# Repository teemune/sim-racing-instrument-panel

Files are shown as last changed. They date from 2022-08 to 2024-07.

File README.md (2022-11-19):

# sim-racing-instrument-panel
 Instruments for sim racing games
 
## SimHub Gear Display
Design files for electronics and FW included.

Works with SimHub Dash Studio, which generates the Arduino code. Standard Arduino bootloader needs to be flashed on the microcontroller first, to make it able to receive a firmware through USB.

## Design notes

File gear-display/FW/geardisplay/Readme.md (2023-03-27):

## Changes from SimHub default config:
### Change 7-segment display configuration:
There is a bug in the J-revision sketch.

The sketch version can be identified by rows:
~~~
// J revision sketch
#define VERSION 'j'
~~~

The byte array is described incorrectly:

~~~
byte g_6c595fontArray[] = {
  // dp-a-b-c-d-e-f-g
  0b00111111, // 0
  0b00000110, // 1
  0b01011011, // 2
  0b01001111, // 3
  0b01110010, // 4
  0b01101101, // 5
  0b01111101, // 6
  0b00000111, // 7
  0b00111111, // 8
  0b01101111, // 9
  0b00000000, // OFF empty
  0b11101111, // REVERSE SPEED
};
~~~

The configuration is actually:
~~~
// dp-g-f-e-d-c-b-a
~~~

to

#### Rev1 PCB:
~~~
byte g_6c595fontArray[] = {
  // a-b-c-d-e-f-g-dp
  0b11111100, // 0        
  0b01100000, // 1            
  0b11011010, // 2
  0b11110010, // 3
  0b01101010, // 4
  0b10110110, // 5
  0b10111110, // 6
  0b11100000, // 7
  0b11111100, // 8
  0b11110110, // 9
  0b00000000, // OFF empty
  0b11101111, // REVERSE SPEED
};
~~~

#### Rev2 PCB:
Designed for SimHub sketch template "J".
~~~
byte g_6c595fontArray[] = {
  // dp-g-f-e-d-c-b-a
  0b00111111, // 0        
  0b00000110, // 1            
  0b01011011, // 2
  0b01001111, // 3
  0b01110010, // 4
  0b01101101, // 5
  0b01111101, // 6
  0b00000111, // 7
  0b00111111, // 8
  0b01101111, // 9
  0b00000000, // OFF empty
  0b11101111, // REVERSE SPEED
};
~~~

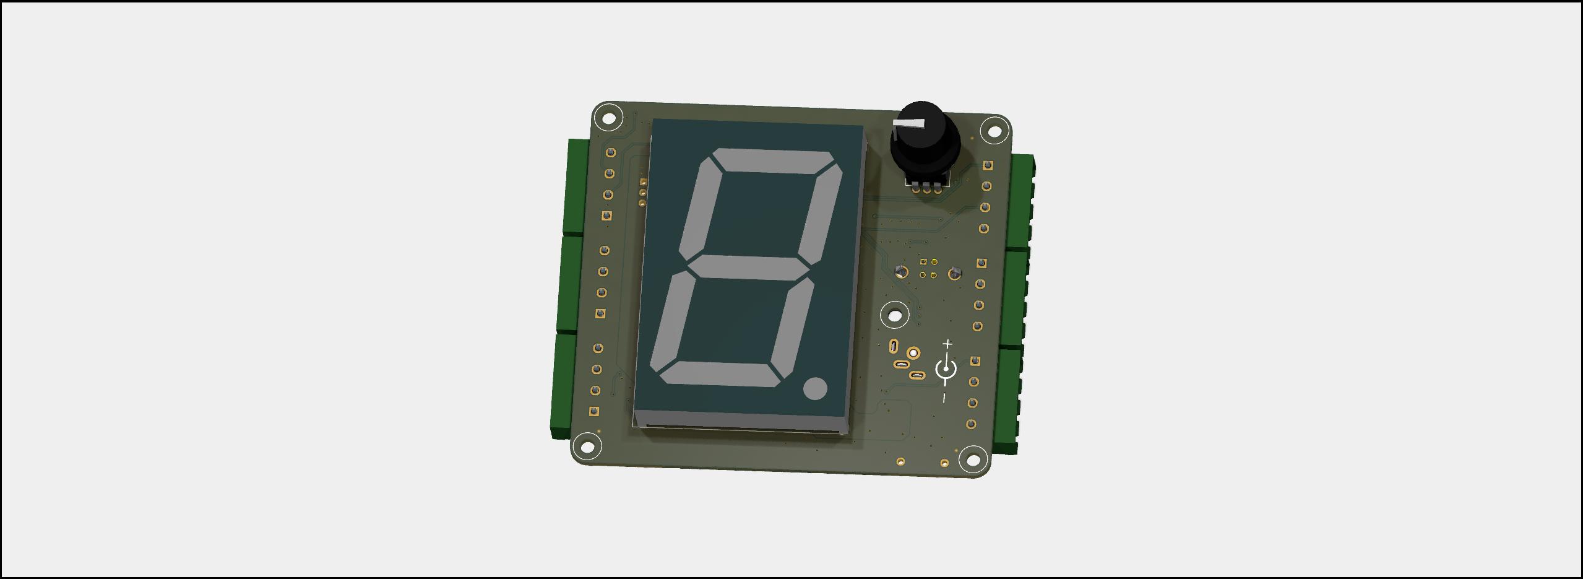
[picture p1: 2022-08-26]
gear-display/PCB/GDBM/pic/GDBM_R.jpg

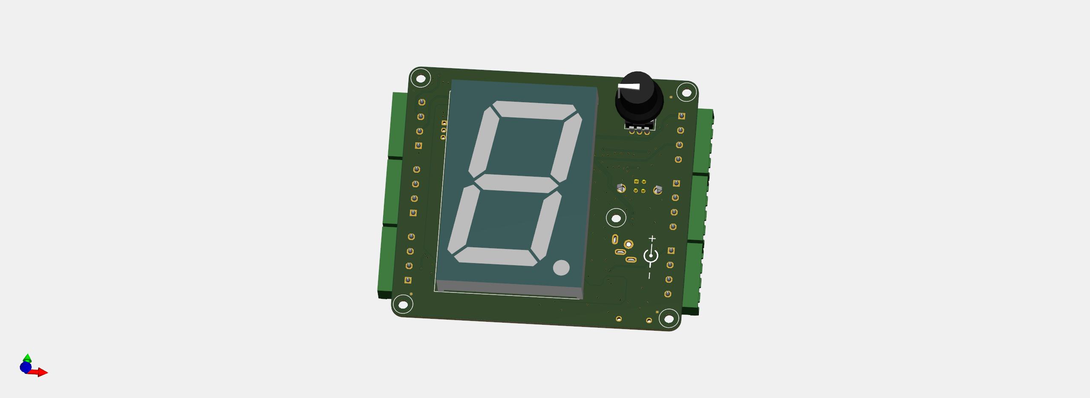
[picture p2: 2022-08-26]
gear-display/PCB/GDBM/pic/GDBM.jpg

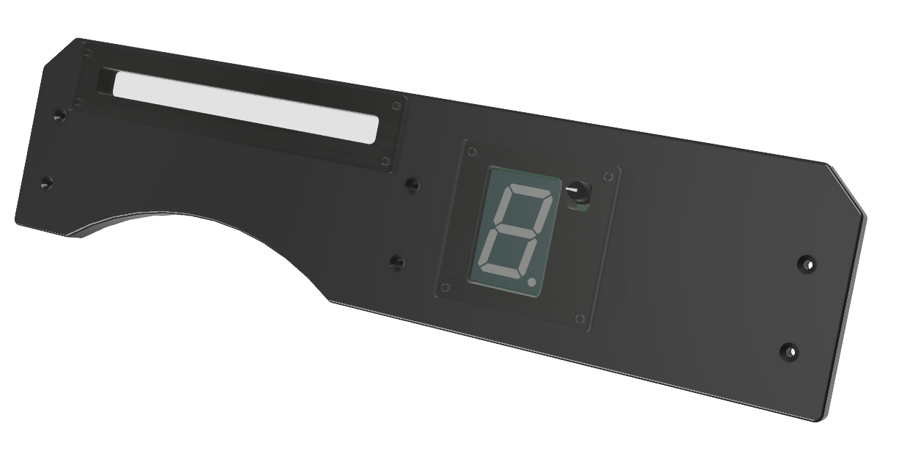
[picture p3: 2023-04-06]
gear-display/Dashboard v6.png

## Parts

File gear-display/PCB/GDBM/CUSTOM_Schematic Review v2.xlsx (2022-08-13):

Product: | Cure Rev B
Review date: | 0.4407638889
Reviewer: | Teemu Latonen
No | Item | Status | Comments
1 | Documentation
1.1 | New components checked for errors | x
1.2 | Schematic and test point comments
1.3 | Revision etc updated | x
1.4 | Change history page updated | x
2 | General design
2.1 | Check that floating pins are ok to be left floating | x
2.2 | Is there room for more bypass capacitors
2.3 | Design rules
2.4 | Combine R and C values and sizes | x
3 | Digital circuits
3.1 | Impedance matching | x
3.2 | Logic voltage levels | x
3.3 | Logic timings during boot up | x
4 | Analog circuits
4.1 | Op amps: Offset voltage, bias current, speed, output load capability | x
 | Capacitive loading | x
4.2 | Input ranges for analog circuits | x
4.3 | Overvoltage situations | x
5 | Power circuits
5.1 | Power outputs are short circuit proof | x
5.2 | Power input is polarity protected | x
5.3 | Fuses and TVSs are added | x
6 | EMC
6.1 | Input and output signals are filtered | x
6.2 | Critical signals (RESET etc) are protected from EMI | x
6.3 | Fast signals are suppressed (e.g. high frequency clocks, SMPS) | x
6.4 | Emissions from SMPS are analyzed and proper countermeasures used
7 | Testing and production
7.1 | Test points, GND connection point
7.2 | 0 Ohm resistors to isolate circuits | x
7.3 | Alignment holes for tester | x
7.4 | All parts are RoHS compliant | x
8 | BOM
8.1 | Component availability and lead times

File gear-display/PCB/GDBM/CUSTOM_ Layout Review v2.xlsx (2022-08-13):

Product: | Cure
Review date: | 10.1.2022
Reviewer: | Teemu Latonen
No | Item | Status | Comments
1 | Markings
1.1 | PN, revision etc marked on board |  | ok
1.2 | Area marked for UL and manufacturer markings
1.3 | Layers marked for 4+ layer boards |  | ok
1.4 | Reference designators |  | ok
1.5 | PCB Build up in drill drawing
2 | Design
2.1 | Spark gaps and clearance cut outs |  | ok
2.2 | Fiducials |  | ok
2.3 | Clerances and creepage distances checked |  | ok
2.4 | Corners rounded (0.5 mm) |  | ok
2.5 | Cable clearances, receptacles fit to connectors |  | ok
2.6 | Component clearances |  | ok
2.7 | Mounting holes |  | ok
2.8 | PCB break away tabs |  | Not needed
2.9 | Polarization of components (pin 1 marked, connectors labeled) |  | Diode footprint could be improved
2.10 | No traces under conductive components |  | ok
2.11 | No direct traces between adjacent pads of IC, if not covered by solder mask |  | ok
2.12 | Tester guidance holes |  | ok
2.13 | > 5 mm distance between test points |  | No test points
2.14 | Reset traces short |  | well…
2.15 | Ground planes for analog circuits |  | ok
2.16 | Impedance matching |  | ok
2.17 | Area for heat sinks or exposed copper on PCB |  | ok
2.18 | Wave soldering requirements
2.19 | Hand soldering requirements |  | not optimal
3 | Documents
3.1 | BOM
3.2 | Gerbers
3.3 | Placement ASCII file
3.4 | Assembly drawing
4 | OTHER
4.1 | PCB and silk color
4.2 | Surface finish

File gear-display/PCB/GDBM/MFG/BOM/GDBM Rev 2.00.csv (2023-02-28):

Source: | C:\GitHubProjects\sim-racing-instrument-panel\gear-display\PCB\GDBM\GDBM.kicad_sch
Date: | 28/02/2023 22.51.25
Tool: | Eeschema (6.0.0)
Generator: | C:\Program Files\KiCad\6.0\bin\scripting\plugins/bom_csv_grouped_by_value.py
Component Count: | 94
Individual Components:
Item | Qty | Reference(s) | Value | LibPart | Footprint | Datasheet | Code | DNP | MFG_PartNo | Manufacturer | Price | Supplier | Supplier_PartNo
 |  | C1 | C_1206_10u_X5R_50V_automotive | KD_Capacitor:C_1206_10u_X5R_50V_automotive | KD_Capacitor:CAPC3216X150N | https://search.murata.co.jp/Ceramy/image/img/A01X/G101/ENG/GRT31CR61H106ME01-01.pdf | 10u | F | GRT31CR61H106ME01L | Murata Electronics | 0.30 | Digi-Key | 490-12457-1-ND
 |  | C2 | C_1206_10u_X5R_50V_automotive | KD_Capacitor:C_1206_10u_X5R_50V_automotive | KD_Capacitor:CAPC3216X150N | https://search.murata.co.jp/Ceramy/image/img/A01X/G101/ENG/GRT31CR61H106ME01-01.pdf | 10u | F | GRT31CR61H106ME01L | Murata Electronics | 0.30 | Digi-Key | 490-12457-1-ND
 |  | C3 | C_1206_10u_X5R_50V_automotive | KD_Capacitor:C_1206_10u_X5R_50V_automotive | KD_Capacitor:CAPC3216X150N | https://search.murata.co.jp/Ceramy/image/img/A01X/G101/ENG/GRT31CR61H106ME01-01.pdf | 10u | F | GRT31CR61H106ME01L | Murata Electronics | 0.30 | Digi-Key | 490-12457-1-ND
 |  | C4 | C_0603_100n_X7R_100V | KD_Capacitor:C_0603_100n_X7R_100V | KD_Capacitor:CAPC1608X90N | https://media.digikey.com/pdf/Data%20Sheets/Samsung%20PDFs/CL10B104KC8NNNC_Spec.pdf | 100n | F | CL10B104KC8NNNC | Samsung Electro-Mechanics | 0.03 | Digi-Key | 1276-6807-1-ND
 |  | C5 | C_0603_100n_X7R_100V | KD_Capacitor:C_0603_100n_X7R_100V | KD_Capacitor:CAPC1608X90N | https://media.digikey.com/pdf/Data%20Sheets/Samsung%20PDFs/CL10B104KC8NNNC_Spec.pdf | 100n | F | CL10B104KC8NNNC | Samsung Electro-Mechanics | 0.03 | Digi-Key | 1276-6807-1-ND
 |  | C6 | C_0603_100n_X7R_100V | KD_Capacitor:C_0603_100n_X7R_100V | KD_Capacitor:CAPC1608X90N | https://media.digikey.com/pdf/Data%20Sheets/Samsung%20PDFs/CL10B104KC8NNNC_Spec.pdf | 100n | F | CL10B104KC8NNNC | Samsung Electro-Mechanics | 0.03 | Digi-Key | 1276-6807-1-ND
 |  | C7 | C_0805_1u_X7R_25V | KD_Capacitor:C_0805_1u_X7R_25V | KD_Capacitor:CAPC2012X135N | https://api.kemet.com/component-edge/download/datasheet/CBR08C279B5GAC.pdf | 1u | F | CL21B105KAFNNNE | Kemet | 0.03 | Digi-Key | 1276-1066-1-ND
 |  | C8 | C_0603_33p_NP0_5%_100V | KD_Capacitor:C_0603_33p_NP0_5%_100V | KD_Capacitor:CAPC1608X90N | http://www.passivecomponent.com/wp-content/uploads/datasheet/WTC_MLCC_General_Purpose.pdf | 33p | F | C0603C330J1GAC7867 | KEMET | 0.05 | Digi-Key | 399-C0603C330J1GAC7867CT-ND
 |  | C9 | C_0805_1u_X7R_25V | KD_Capacitor:C_0805_1u_X7R_25V | KD_Capacitor:CAPC2012X135N | https://api.kemet.com/component-edge/download/datasheet/CBR08C279B5GAC.pdf | 1u | F | CL21B105KAFNNNE | Kemet | 0.03 | Digi-Key | 1276-1066-1-ND
 |  | C10 | C_0603_33p_NP0_5%_100V | KD_Capacitor:C_0603_33p_NP0_5%_100V | KD_Capacitor:CAPC1608X90N | http://www.passivecomponent.com/wp-content/uploads/datasheet/WTC_MLCC_General_Purpose.pdf | 33p | F | C0603C330J1GAC7867 | KEMET | 0.05 | Digi-Key | 399-C0603C330J1GAC7867CT-ND
 |  | C11 | C_0805_1u_X7R_25V | KD_Capacitor:C_0805_1u_X7R_25V | KD_Capacitor:CAPC2012X135N | https://api.kemet.com/component-edge/download/datasheet/CBR08C279B5GAC.pdf | 1u | F | CL21B105KAFNNNE | Kemet | 0.03 | Digi-Key | 1276-1066-1-ND
 |  | C12 | C_1206_10u_X5R_50V_automotive | KD_Capacitor:C_1206_10u_X5R_50V_automotive | KD_Capacitor:CAPC3216X150N | https://search.murata.co.jp/Ceramy/image/img/A01X/G101/ENG/GRT31CR61H106ME01-01.pdf | 10u | F | GRT31CR61H106ME01L | Murata Electronics | 0.30 | Digi-Key | 490-12457-1-ND
 |  | C13 | C_0603_100n_X7R_100V | KD_Capacitor:C_0603_100n_X7R_100V | KD_Capacitor:CAPC1608X90N | https://media.digikey.com/pdf/Data%20Sheets/Samsung%20PDFs/CL10B104KC8NNNC_Spec.pdf | 100n | F | CL10B104KC8NNNC | Samsung Electro-Mechanics | 0.03 | Digi-Key | 1276-6807-1-ND
 |  | C14 | C_0603_100n_X7R_100V | KD_Capacitor:C_0603_100n_X7R_100V | KD_Capacitor:CAPC1608X90N | https://media.digikey.com/pdf/Data%20Sheets/Samsung%20PDFs/CL10B104KC8NNNC_Spec.pdf | 100n | F | CL10B104KC8NNNC | Samsung Electro-Mechanics | 0.03 | Digi-Key | 1276-6807-1-ND
 |  | C15 | C_0805_DNP | KD_Capacitor:C_0805_DNP | KD_Capacitor:CAPC2012X135N_DNP | https://api.kemet.com/component-edge/download/datasheet/CBR08C279B5GAC.pdf | DNP | T | DNP | DNP | 0.00 | DNP | DNP
 |  | C16 | C_1206_10u_X5R_50V_automotive | KD_Capacitor:C_1206_10u_X5R_50V_automotive | KD_Capacitor:CAPC3216X150N | https://search.murata.co.jp/Ceramy/image/img/A01X/G101/ENG/GRT31CR61H106ME01-01.pdf | 10u | F | GRT31CR61H106ME01L | Murata Electronics | 0.30 | Digi-Key | 490-12457-1-ND
 |  | C17 | C_1206_10u_X5R_50V_automotive | KD_Capacitor:C_1206_10u_X5R_50V_automotive | KD_Capacitor:CAPC3216X150N | https://search.murata.co.jp/Ceramy/image/img/A01X/G101/ENG/GRT31CR61H106ME01-01.pdf | 10u | F | GRT31CR61H106ME01L | Murata Electronics | 0.30 | Digi-Key | 490-12457-1-ND
 |  | C18 | C_0603_100n_X7R_100V | KD_Capacitor:C_0603_100n_X7R_100V | KD_Capacitor:CAPC1608X90N | https://media.digikey.com/pdf/Data%20Sheets/Samsung%20PDFs/CL10B104KC8NNNC_Spec.pdf | 100n | F | CL10B104KC8NNNC | Samsung Electro-Mechanics | 0.03 | Digi-Key | 1276-6807-1-ND
 |  | C19 | C_0603_100n_X7R_100V | KD_Capacitor:C_0603_100n_X7R_100V | KD_Capacitor:CAPC1608X90N | https://media.digikey.com/pdf/Data%20Sheets/Samsung%20PDFs/CL10B104KC8NNNC_Spec.pdf | 100n | F | CL10B104KC8NNNC | Samsung Electro-Mechanics | 0.03 | Digi-Key | 1276-6807-1-ND
 |  | C20 | C_0805_DNP | KD_Capacitor:C_0805_DNP | KD_Capacitor:CAPC2012X135N_DNP | https://api.kemet.com/component-edge/download/datasheet/CBR08C279B5GAC.pdf | DNP | T | DNP | DNP | 0.00 | DNP | DNP
 |  | C21 | C_0805_1u_X7R_25V | KD_Capacitor:C_0805_1u_X7R_25V | KD_Capacitor:CAPC2012X135N | https://api.kemet.com/component-edge/download/datasheet/CBR08C279B5GAC.pdf | 1u | F | CL21B105KAFNNNE | Kemet | 0.03 | Digi-Key | 1276-1066-1-ND
 |  | C22 | C_0805_22u_X5R_10V | KD_Capacitor:C_0805_22u_X5R_10V | KD_Capacitor:CAPC2012X135N | https://www.samsungsem.com/kr/support/product-search/mlcc/CL21A226MPQNNNE.jsp | 22u | F | CL21A226MPQNNNE | Samsung Electro-Mechanics | 0.15 | Digi-Key | 1276-2910-1-ND
 |  | C23 | C_0603_10n_X7R_100V | KD_Capacitor:C_0603_10n_X7R_100V | KD_Capacitor:CAPC1608X90N |  | 10n | F | C1608X7R2A103K080AA | TDK Corporation | 0.05 | Digi-Key | 445-1304-1-ND
 |  | C24 | C_0603_10n_X7R_100V | KD_Capacitor:C_0603_10n_X7R_100V | KD_Capacitor:CAPC1608X90N |  | 10n | F | C1608X7R2A103K080AA | TDK Corporation | 0.05 | Digi-Key | 445-1304-1-ND
 |  | C25 | C_1206_10u_X5R_50V_automotive | KD_Capacitor:C_1206_10u_X5R_50V_automotive | KD_Capacitor:CAPC3216X150N | https://search.murata.co.jp/Ceramy/image/img/A01X/G101/ENG/GRT31CR61H106ME01-01.pdf | 10u | F | GRT31CR61H106ME01L | Murata Electronics | 0.30 | Digi-Key | 490-12457-1-ND
 |  | D1 | Schottky_30V_1A_Toshiba_CUS10S30 | KD_Diode:Schottky_30V_1A_Toshiba_CUS10S30 | KD_Diode:D_SOD-323 | https://toshiba.semicon-storage.com/info/docget.jsp?did=14077&prodName=CUS10S30 | CUS10S30,H3F | F | CUS10S30,H3F | Toshiba Semiconductor and Storage | 0.2 | Digi-Key | CUS10S30H3FCT-ND
 |  | D2 | TVS_12V_LF_SMAJ12CA | KD_Diode:TVS_12V_LF_SMAJ12CA | KD_Diode:DIOC530X280X230_SMA_A | https://media.digikey.com/pdf/Data%20Sheets/AVX%20PDFs/Transient%20Suppression%20Diodes.pdf | SMAJ12A | F | SMAJ12A | Littelfuse Inc. | 0.3 | Digi-Key | SMAJ12ALFCT-ND
 |  | D3 | 0603_Green_Clear_LTST-C190KGKT | KD_Led:0603_Green_Clear_LTST-C190KGKT | KD_Diode:DIOC1608X70 | https://optoelectronics.liteon.com/upload/download/DS22-2000-074/LTST-C190KGKT.PDF | Green Clear | F | LTST-C190KGKT | Lite-On Inc. | 0.05 | Digi-Key | 160-1435-1-ND
 |  | D4 | TVS_5V5_DRTR5V0U4S-7-M | KD_Diode:TVS_5V5_DRTR5V0U4S-7-M | KD_Package_TO_SOT_SMD:SOT-363_SC-70-6 | https://www.diodes.com/assets/Datasheets/DRTR5V0U4S.pdf | DRTR5V0U4S-7 | F | DRTR5V0U4S-7 | Diodes Incorporated | 0.30 | Digi-Key | DRTR5V0U4S-7DICT-ND
 |  | D5 | 7seg_70mm_CA_Lumex_LDS-AD16RI | KD_Display:7seg_70mm_CA_Lumex_LDS-AD16RI | KD_Display:7seg_70mm_Kingbright_SC23-11SURKWA | datasheet | LDS-AD16RI | F | LDS-AD16RI | Lumex Opto/Components Inc. | 13 | Digi-Key | 67-1493-ND
 |  | D6 | Schottky_30V_1A_Toshiba_CUS10S30 | KD_Diode:Schottky_30V_1A_Toshiba_CUS10S30 | KD_Diode:D_SOD-323 | https://toshiba.semicon-storage.com/info/docget.jsp?did=14077&prodName=CUS10S30 | CUS10S30,H3F | F | CUS10S30,H3F | Toshiba Semiconductor and Storage | 0.2 | Digi-Key | CUS10S30H3FCT-ND
 |  | D7 | Schottky_30V_1A_Toshiba_CUS10S30 | KD_Diode:Schottky_30V_1A_Toshiba_CUS10S30 | KD_Diode:D_SOD-323 | https://toshiba.semicon-storage.com/info/docget.jsp?did=14077&prodName=CUS10S30 | CUS10S30,H3F | F | CUS10S30,H3F | Toshiba Semiconductor and Storage | 0.2 | Digi-Key | CUS10S30H3FCT-ND
 |  | F1 | Fuse_1A_C1F_1 | KD_Devices_Other:Fuse_1A_C1F_1 | KD_Resistor:RESC3216X70N | https://belfuse.com/resources/datasheets/circuitprotection/ds-cp-c1f-series.pdf | Fuse 1 A | F | C1F 1 | Bel Fuse Inc. | 0.15 | Digi-Key | 507-1878-1-ND
 |  | FB1 | Ferrite_250mA_Murata_BLM15HG102SN1D | KD_Inductor:Ferrite_250mA_Murata_BLM15HG102SN1D | KD_Inductor:INDC1005X55N | datasheet | BLM15HG102SN1D | F | BLM15HG102SN1D | Murata Electronics | 0.10 | Digi-Key | 490-3999-1-ND
 |  | H1 | NPTH_3.2_M3_Clearance | KD_Mechanical_Mounting_Hole:NPTH_3.2_M3_Clearance | KD_Mechanical_Mounting_Hole:NPTH_3.2mm_M3_clearance |  | 3.2 mm hole | T | DNP | DNP | 0.00 | DNP | DNP
 |  | H3 | NPTH_3.2_M3_Clearance | KD_Mechanical_Mounting_Hole:NPTH_3.2_M3_Clearance | KD_Mechanical_Mounting_Hole:NPTH_3.2mm_M3_clearance |  | 3.2 mm hole | T | DNP | DNP | 0.00 | DNP | DNP
 |  | H4 | NPTH_3.2_M3_Clearance | KD_Mechanical_Mounting_Hole:NPTH_3.2_M3_Clearance | KD_Mechanical_Mounting_Hole:NPTH_3.2mm_M3_clearance |  | 3.2 mm hole | T | DNP | DNP | 0.00 | DNP | DNP
 |  | H5 | NPTH_3.2_M3_Clearance | KD_Mechanical_Mounting_Hole:NPTH_3.2_M3_Clearance | KD_Mechanical_Mounting_Hole:NPTH_3.2mm_M3_clearance |  | 3.2 mm hole | T | DNP | DNP | 0.00 | DNP | DNP
 |  | H6 | NPTH_3.2_M3_Clearance | KD_Mechanical_Mounting_Hole:NPTH_3.2_M3_Clearance | KD_Mechanical_Mounting_Hole:NPTH_3.2mm_M3_clearance |  | 3.2 mm hole | T | DNP | DNP | 0.00 | DNP | DNP
 |  | J1 | Con_Screw_1x04_691313510004 | KD_Connector_Screw:Con_Screw_1x04_691313510004 | KD_Connector_Screw:CON_508_1X04_691313510004_Mated | https://www.we-online.com/katalog/datasheet/6913135100xx.pdf | 1x04 | F | 691313510004 | Würth Elektronik | 0.3 | Digi-Key | 732-2072-ND
 |  | J2 | Con_Screw_1x04_691313510004 | KD_Connector_Screw:Con_Screw_1x04_691313510004 | KD_Connector_Screw:CON_508_1X04_691313510004_Mated | https://www.we-online.com/katalog/datasheet/6913135100xx.pdf | 1x04 | F | 691313510004 | Würth Elektronik | 0.3 | Digi-Key | 732-2072-ND
 |  | J3 | DC_2.1_5.5_54-00286 | KD_Connector_Circular:DC_2.1_5.5_54-00286 | KD_Connector_Circular:CON_DC_2.1_5.5_Tensility_54-00286 | http://www.tensility.com/pdffiles/54-00286.pdf | 2.1 mm DC | F | 54-00286 | CUI Devices | 0.7 | Digi-Key | 839-54-00286-ND
 |  | J4 | Con_Screw_1x04_691313510004 | KD_Connector_Screw:Con_Screw_1x04_691313510004 | KD_Connector_Screw:CON_508_1X04_691313510004_Mated | https://www.we-online.com/katalog/datasheet/6913135100xx.pdf | 1x04 | F | 691313510004 | Würth Elektronik | 0.3 | Digi-Key | 732-2072-ND
 |  | J5 | Con_Screw_1x04_691313510004 | KD_Connector_Screw:Con_Screw_1x04_691313510004 | KD_Connector_Screw:CON_508_1X04_691313510004_Mated | https://www.we-online.com/katalog/datasheet/6913135100xx.pdf | 1x04 | F | 691313510004 | Würth Elektronik | 0.3 | Digi-Key | 732-2072-ND
 |  | J6 | Con_Screw_1x04_691313510004 | KD_Connector_Screw:Con_Screw_1x04_691313510004 | KD_Connector_Screw:CON_508_1X04_691313510004_Mated | https://www.we-online.com/katalog/datasheet/6913135100xx.pdf | 1x04 | F | 691313510004 | Würth Elektronik | 0.3 | Digi-Key | 732-2072-ND
 |  | J7 | Con_Screw_1x04_691313510004 | KD_Connector_Screw:Con_Screw_1x04_691313510004 | KD_Connector_Screw:CON_508_1X04_691313510004_Mated | https://www.we-online.com/katalog/datasheet/6913135100xx.pdf | 1x04 | F | 691313510004 | Würth Elektronik | 0.3 | Digi-Key | 732-2072-ND
 |  | J8 | USB_B_V_Adam_USB-B-S-VT | KD_Connector_USB_HDMI_Etc:USB_B_V_Adam_USB-B-S-VT | KD_Connector_USB_HDMI_Etc:USB_B_Vertical_Adam_USB-B-S-VT | https://app.adam-tech.com/products/download/data_sheet/195855/usb-b-s-vt-data-sheet.pdf | USB Mini B | F | USB-B-S-VT | Adam Tech | 1 | Digi-Key | 2057-USB-B-S-VT-ND
 |  | M1 | Knob_6mm_BL_RED_CLIFF_CL170842CR | KD_Mechanical:Knob_6mm_BL_RED_CLIFF_CL170842CR | KD_Mechanical:Knob_CLIFF_CL170842CR |  | CL170842CR | F | CL170842CR | CLIFF Electronic Components Ltd | 1 | Digi-Key | 3185-CL170842CR-ND
 |  | Q1 | PMOS_30V_4A1_SIL3407-TP | KD_Transistor_FET:PMOS_30V_4A1_SIL3407-TP | KD_Package_TO_SOT_SMD:SOT95P280X120-6RN | https://www.mccsemi.com/pdf/Products/SIL3407(SOT23-6L).pdf | SIL3407-TP | F | SIL3407-TP | Micro Commercial Co | 0.4 | Digi-Key | 353-SIL3407-TPCT-ND
 |  | R1 | R_0805_DNP | KD_Resistor:R_0805_DNP | KD_Resistor:RESC2012X60N_DNP |  | DNP | T | DNP | DNP | 0.00 | DNP | DNP
 |  | R2 | R_0603_22k_1% | KD_Resistor:R_0603_22k_1% | KD_Resistor:RESC1608X55N | https://www.yageo.com/upload/media/product/productsearch/datasheet/rchip/PYu-RC_Group_51_RoHS_L_11.pdf | 22k | F | 311-22.0KHRCT-ND | YAGEO | 0.01 | Digi-Key | 311-22.0KHRCT-ND
 |  | R3 | R_0603_360_1% | KD_Resistor:R_0603_360_1% | KD_Resistor:RESC1608X55N | https://www.yageo.com/upload/media/product/productsearch/datasheet/rchip/PYu-RT_1-to-0.01_RoHS_L_12.pdf | 360 | F | RT0603FRE07360RL | YAGEO | 0.02 | Digi-Key | 13-RT0603FRE07360RLCT-ND
 |  | R4 | R_0603_22k_1% | KD_Resistor:R_0603_22k_1% | KD_Resistor:RESC1608X55N | https://www.yageo.com/upload/media/product/productsearch/datasheet/rchip/PYu-RC_Group_51_RoHS_L_11.pdf | 22k | F | 311-22.0KHRCT-ND | YAGEO | 0.01 | Digi-Key | 311-22.0KHRCT-ND
 |  | R5 | R_0603_DNP | KD_Resistor:R_0603_DNP | KD_Resistor:RESC1608X55N_DNP |  | DNP | T | DNP | DNP | 0.00 | DNP | DNP
 |  | R6 | R_0603_360_1% | KD_Resistor:R_0603_360_1% | KD_Resistor:RESC1608X55N | https://www.yageo.com/upload/media/product/productsearch/datasheet/rchip/PYu-RT_1-to-0.01_RoHS_L_12.pdf | 360 | F | RT0603FRE07360RL | YAGEO | 0.02 | Digi-Key | 13-RT0603FRE07360RLCT-ND
 |  | R7 | R_0603_360_1% | KD_Resistor:R_0603_360_1% | KD_Resistor:RESC1608X55N | https://www.yageo.com/upload/media/product/productsearch/datasheet/rchip/PYu-RT_1-to-0.01_RoHS_L_12.pdf | 360 | F | RT0603FRE07360RL | YAGEO | 0.02 | Digi-Key | 13-RT0603FRE07360RLCT-ND
 |  | R8 | R_0402_DNP | KD_Resistor:R_0402_DNP | KD_Resistor:RESC1005X40N |  | DNP | T | DNP | DNP | 0.00 | DNP | DNP
 |  | R9 | R_0603_10_5% | KD_Resistor:R_0603_10_5% | KD_Resistor:RESC1608X55N | https://www.te.com/commerce/DocumentDelivery/DDEController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 | 10 | F | WR06X100 JTL | Walsin Technology Corporation | 0.01 | Digi-Key | 1292-WR06X100JTLCT-ND
 |  | R10 | R_0603_10_5% | KD_Resistor:R_0603_10_5% | KD_Resistor:RESC1608X55N | https://www.te.com/commerce/DocumentDelivery/DDEController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 | 10 | F | WR06X100 JTL | Walsin Technology Corporation | 0.01 | Digi-Key | 1292-WR06X100JTLCT-ND
 |  | R11 | R_1206_191_1% | KD_Resistor:R_1206_191_1% | KD_Resistor:RESC3216X70N | https://www.yageo.com/upload/media/product/productsearch/datasheet/rchip/PYu-RC_Group_51_RoHS_L_11.pdf | 191 | F | RC1206FR-07191RL | YAGEO | 0.05 | Digi-Key | 311-191FRCT-ND
 |  | R12 | R_1206_191_1% | KD_Resistor:R_1206_191_1% | KD_Resistor:RESC3216X70N | https://www.yageo.com/upload/media/product/productsearch/datasheet/rchip/PYu-RC_Group_51_RoHS_L_11.pdf | 191 | F | RC1206FR-07191RL | YAGEO | 0.05 | Digi-Key | 311-191FRCT-ND
 |  | R13 | R_1206_191_1% | KD_Resistor:R_1206_191_1% | KD_Resistor:RESC3216X70N | https://www.yageo.com/upload/media/product/productsearch/datasheet/rchip/PYu-RC_Group_51_RoHS_L_11.pdf | 191 | F | RC1206FR-07191RL | YAGEO | 0.05 | Digi-Key | 311-191FRCT-ND
 |  | R14 | R_1206_191_1% | KD_Resistor:R_1206_191_1% | KD_Resistor:RESC3216X70N | https://www.yageo.com/upload/media/product/productsearch/datasheet/rchip/PYu-RC_Group_51_RoHS_L_11.pdf | 191 | F | RC1206FR-07191RL | YAGEO | 0.05 | Digi-Key | 311-191FRCT-ND
 |  | R15 | R_0603_22k_1% | KD_Resistor:R_0603_22k_1% | KD_Resistor:RESC1608X55N | https://www.yageo.com/upload/media/product/productsearch/datasheet/rchip/PYu-RC_Group_51_RoHS_L_11.pdf | 22k | F | 311-22.0KHRCT-ND | YAGEO | 0.01 | Digi-Key | 311-22.0KHRCT-ND
 |  | R16 | R_1206_191_1% | KD_Resistor:R_1206_191_1% | KD_Resistor:RESC3216X70N | https://www.yageo.com/upload/media/product/productsearch/datasheet/rchip/PYu-RC_Group_51_RoHS_L_11.pdf | 191 | F | RC1206FR-07191RL | YAGEO | 0.05 | Digi-Key | 311-191FRCT-ND
 |  | R17 | R_1206_191_1% | KD_Resistor:R_1206_191_1% | KD_Resistor:RESC3216X70N | https://www.yageo.com/upload/media/product/productsearch/datasheet/rchip/PYu-RC_Group_51_RoHS_L_11.pdf | 191 | F | RC1206FR-07191RL | YAGEO | 0.05 | Digi-Key | 311-191FRCT-ND
 |  | R18 | R_1206_191_1% | KD_Resistor:R_1206_191_1% | KD_Resistor:RESC3216X70N | https://www.yageo.com/upload/media/product/productsearch/datasheet/rchip/PYu-RC_Group_51_RoHS_L_11.pdf | 191 | F | RC1206FR-07191RL | YAGEO | 0.05 | Digi-Key | 311-191FRCT-ND
 |  | R19 | R_1206_191_1% | KD_Resistor:R_1206_191_1% | KD_Resistor:RESC3216X70N | https://www.yageo.com/upload/media/product/productsearch/datasheet/rchip/PYu-RC_Group_51_RoHS_L_11.pdf | 191 | F | RC1206FR-07191RL | YAGEO | 0.05 | Digi-Key | 311-191FRCT-ND
 |  | R20 | R_0805_0_automotive | KD_Resistor:R_0805_0_automotive | KD_Resistor:RESC2012X60N | https://www.seielect.com/catalog/sei-rmcf_rmcp.pdf | 0 | F | RMCF0805ZT0R00 | Stackpole Electronics Inc | 0.01 | Digi-Key | RMCF0805ZT0R00CT-ND
 |  | R21 | R_0805_0_automotive | KD_Resistor:R_0805_0_automotive | KD_Resistor:RESC2012X60N | https://www.seielect.com/catalog/sei-rmcf_rmcp.pdf | 0 | F | RMCF0805ZT0R00 | Stackpole Electronics Inc | 0.01 | Digi-Key | RMCF0805ZT0R00CT-ND
 |  | R22 | R_0805_DNP | KD_Resistor:R_0805_DNP | KD_Resistor:RESC2012X60N_DNP | https://www.seielect.com/catalog/sei-rmcf_rmcp.pdf | DNP | T | DNP | DNP | 0.00 | DNP | DNP
 |  | R23 | R_0805_0_automotive | KD_Resistor:R_0805_0_automotive | KD_Resistor:RESC2012X60N | https://www.seielect.com/catalog/sei-rmcf_rmcp.pdf | 0 | F | RMCF0805ZT0R00 | Stackpole Electronics Inc | 0.01 | Digi-Key | RMCF0805ZT0R00CT-ND
 |  | R24 | R_0805_0_automotive | KD_Resistor:R_0805_0_automotive | KD_Resistor:RESC2012X60N | https://www.seielect.com/catalog/sei-rmcf_rmcp.pdf | 0 | F | RMCF0805ZT0R00 | Stackpole Electronics Inc | 0.01 | Digi-Key | RMCF0805ZT0R00CT-ND
 |  | R25 | R_0805_0_automotive | KD_Resistor:R_0805_0_automotive | KD_Resistor:RESC2012X60N | https://www.seielect.com/catalog/sei-rmcf_rmcp.pdf | 0 | F | RMCF0805ZT0R00 | Stackpole Electronics Inc | 0.01 | Digi-Key | RMCF0805ZT0R00CT-ND
 |  | R26 | R_0603_22k_1% | KD_Resistor:R_0603_22k_1% | KD_Resistor:RESC1608X55N | https://www.yageo.com/upload/media/product/productsearch/datasheet/rchip/PYu-RC_Group_51_RoHS_L_11.pdf | 22k | F | 311-22.0KHRCT-ND | YAGEO | 0.01 | Digi-Key | 311-22.0KHRCT-ND
 |  | R27 | R_0603_22k_1% | KD_Resistor:R_0603_22k_1% | KD_Resistor:RESC1608X55N | https://www.yageo.com/upload/media/product/productsearch/datasheet/rchip/PYu-RC_Group_51_RoHS_L_11.pdf | 22k | F | 311-22.0KHRCT-ND | YAGEO | 0.01 | Digi-Key | 311-22.0KHRCT-ND
 |  | R28 | Pot_V_10k_CUI_PT01-D120K2-B103 | KD_Resistor:Pot_V_50k_CUI_PT01-D225D-A503 | KD_Resistor:Potentiometer_CUI_PT01-DX20K2-XXXX | https://www.cuidevices.com/product/resource/pt01.pdf | 50k | F | PT01-D225D-A503 | CUI Devices | 0.77 | Digi-Key | 2223-PT01-D225D-A503-ND
 |  | R29 | R_0603_DNP | KD_Resistor:R_0603_DNP | KD_Resistor:RESC1608X55N_DNP |  | DNP | T | DNP | DNP | 0.00 | DNP | DNP
 |  | R30 | R_0603_DNP | KD_Resistor:R_0603_DNP | KD_Resistor:RESC1608X55N_DNP |  | DNP | T | DNP | DNP | 0.00 | DNP | DNP
 |  | R31 | R_0402_4700_1% | KD_Resistor:R_0402_4700_1% | KD_Resistor:RESC1005X40N | https://www.te.com/commerce/DocumentDelivery/DDEController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 | 4k7 | F | CR0402-FX-4701GLF | Bourns Inc. | 0.01 | Digi-Key | CR0402-FX-4701GLFCT-ND
 |  | R32 | R_0402_4700_1% | KD_Resistor:R_0402_4700_1% | KD_Resistor:RESC1005X40N | https://www.te.com/commerce/DocumentDelivery/DDEController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 | 4k7 | F | CR0402-FX-4701GLF | Bourns Inc. | 0.01 | Digi-Key | CR0402-FX-4701GLFCT-ND
 |  | R33 | R_0805_1200_5% | KD_Resistor:R_0805_1200_5% | KD_Resistor:RESC2012X60N | https://www.seielect.com/catalog/sei-rmcf_rmcp.pdf | 1200 | F | RMCF0805FT1K20 | Stackpole Electronics Inc | 0.01 | Digi-Key | RMCF0805FT1K20CT-ND
 |  | TP1 | TestPoint_2.5mm_Round | KD_Connector_Pads:TestPoint_2.5mm_Round | KD_Connector_Pads:TestPoint_Pad_D2.5mm | DNP | DNP | T | DNP | DNP | 0.00 | DNP | DNP
 |  | TP2 | TestPoint_2.5mm_Round | KD_Connector_Pads:TestPoint_2.5mm_Round | KD_Connector_Pads:TestPoint_Pad_D2.5mm | DNP | DNP | T | DNP | DNP | 0.00 | DNP | DNP
 |  | U1 | DC_DC_5V_2A0_GAPTEC_OKI-78SR-5_H | KD_IC_Regulator_DC_Converter:DC_DC_5V_2A0_GAPTEC_OKI-78SR-5_H | KD_IC_DCDC_Converter:DC_DC_GAPTEC_OKI-78SR-5_H | https://gaptec-electronic.com/datenblaetter/LMS78_2.0R.pdf | LMS78_05-2.0R | F | LMS78_05-2.0R | GAPTEC Electronic | 5 | Digi-Key | 3182-LMS78_05-2.0R-ND
 |  | U2 | ATmega32U4-AU | KD_IC_MCU:ATmega32U4-AU | KD_Package_QFP:QFP80P1200X1200X120-44R_N | http://ww1.microchip.com/downloads/en/DeviceDoc/Atmel-7766-8-bit-AVR-ATmega16U4-32U4_Summary.pdf | ATMEGA32U4-AU | F | ATMEGA32U4-AU | Microchip Technology | 5.3 | Digi-Key | ATMEGA32U4-AU-ND
 |  | U3 | Gate_Driver_MCP1401T-E-OT | KD_IC_Buffer_Driver_Interface:Gate_Driver_MCP1401T-E-OT | KD_Package_TO_SOT_SMD:SOT95P280X145-5N | https://ww1.microchip.com/downloads/en/DeviceDoc/20002052D.pdf | MCP1401 | F | MCP1401T-E/OT | Microchip Technology | 0.7 | Digi-Key | MCP1401T-E/OTCT-ND
 |  | U4 | Shift_register_OC_8bit_STPIC6D595MTR | KD_IC_Buffer_Driver_Interface:Shift_register_OC_8bit_STPIC6D595MTR | KD_Package_SO:SOIC127P640X200-16N | https://www.st.com/content/ccc/resource/technical/document/datasheet/e5/1c/d3/4a/66/f5/41/dc/CD00163738.pdf/files/CD00163738.pdf/jcr:content/translations/en.C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 | STPIC6D595MTR | F | STPIC6D595MTR | STMicroelectronics | 0.9 | Digi-Key | 497-6329-1-ND
 |  | U5 | Timer_Oscillator_TLC555CDG4 | KD_IC_Other:Timer_Oscillator_TLC555CDG4 | KD_Package_SO:SOIC127P600X175-8 | https://www.ti.com/general/docs/suppproductinfo.tsp?distId=10 | TLC555CDG4 | F | TLC555CDG4 | Texas Instruments | 0.9 | Digi-Key | 296-52992-ND
 |  | U8 | Buffer_74LVC125AS14-13_DIODES | KD_IC_Buffer_Driver_Interface:Buffer_74LVC125AS14-13_DIODES | KD_Package_SO:SOIC127P600X175-14N | https://www.diodes.com/assets/Datasheets/74LVC125A.pdf | 74LVC125AS14-13 | F | 74LVC125AS14-13 | Diodes Incorporated | 0.4 | Digi-Key | 74LVC125AS14-13DICT-ND
 |  | X1 | Programming_AVR_ISP_Staggered_Holes | KD_Connector_Special:Programming_AVR_ISP_Staggered_Holes | KD_Connector_Pads:CON_PINHD_1X06_TH_OFFSET | datasheet | AVR ISP | T | DNP | DNP | 0.00 | DNP | DNP
 |  | X2 | CON_1x04_TH_staggered | KD_Connector_Pads:CON_1x04_TH_staggered | KD_Connector_Pads:CON_PINHD_1X04_TH_OFFSET |  | 1x04 DNP | T | DNP | DNP | 0.00 | DNP | DNP
 |  | X3 | CON_GND_Probe_Hook | KD_Connector_Pads:CON_GND_Probe_Hook | KD_Connector_Pads:GND_HOOK_M |  | DNP | T | DNP | DNP | 0.00 | DNP | DNP
 |  | Y1 | Crystal_16M_AS-16.000-18-SMD-TR | KD_Oscillator:Crystal_16M_AS-16.000-18-SMD-TR | KD_Oscillator:OSC_CRYSTAL_HC49_US_N | https://www.raltron.com/webproducts/specs/CRYSTAL/AS-16.000-18-SMD-TR.pdf | 16 MHz | F | AS-16.000-18-SMD-TR | Raltron Electronics | 0.00 | Digi-Key | 2151-AS-16.000-18-SMD-TRCT-ND
Collated Components:
Item | Qty | Reference(s) | Value | LibPart | Footprint | Datasheet | Code | DNP | MFG_PartNo | Manufacturer | Price | Supplier | Supplier_PartNo
1 | 7 | C1, C2, C3, C12, C16, C17, C25 | C_1206_10u_X5R_50V_automotive | KD_Capacitor:C_1206_10u_X5R_50V_automotive | KD_Capacitor:CAPC3216X150N | https://search.murata.co.jp/Ceramy/image/img/A01X/G101/ENG/GRT31CR61H106ME01-01.pdf | 10u | F | GRT31CR61H106ME01L | Murata Electronics | 0.30 | Digi-Key | 490-12457-1-ND
2 | 7 | C4, C5, C6, C13, C14, C18, C19 | C_0603_100n_X7R_100V | KD_Capacitor:C_0603_100n_X7R_100V | KD_Capacitor:CAPC1608X90N | https://media.digikey.com/pdf/Data%20Sheets/Samsung%20PDFs/CL10B104KC8NNNC_Spec.pdf | 100n | F | CL10B104KC8NNNC | Samsung Electro-Mechanics | 0.03 | Digi-Key | 1276-6807-1-ND
3 | 4 | C7, C9, C11, C21 | C_0805_1u_X7R_25V | KD_Capacitor:C_0805_1u_X7R_25V | KD_Capacitor:CAPC2012X135N | https://api.kemet.com/component-edge/download/datasheet/CBR08C279B5GAC.pdf | 1u | F | CL21B105KAFNNNE | Kemet | 0.03 | Digi-Key | 1276-1066-1-ND
4 | 2 | C8, C10 | C_0603_33p_NP0_5%_100V | KD_Capacitor:C_0603_33p_NP0_5%_100V | KD_Capacitor:CAPC1608X90N | http://www.passivecomponent.com/wp-content/uploads/datasheet/WTC_MLCC_General_Purpose.pdf | 33p | F | C0603C330J1GAC7867 | KEMET | 0.05 | Digi-Key | 399-C0603C330J1GAC7867CT-ND
5 | 2 | C15, C20 | C_0805_DNP | KD_Capacitor:C_0805_DNP | KD_Capacitor:CAPC2012X135N_DNP | https://api.kemet.com/component-edge/download/datasheet/CBR08C279B5GAC.pdf | DNP | T | DNP | DNP | 0.00 | DNP | DNP
6 | 1 | C22 | C_0805_22u_X5R_10V | KD_Capacitor:C_0805_22u_X5R_10V | KD_Capacitor:CAPC2012X135N | https://www.samsungsem.com/kr/support/product-search/mlcc/CL21A226MPQNNNE.jsp | 22u | F | CL21A226MPQNNNE | Samsung Electro-Mechanics | 0.15 | Digi-Key | 1276-2910-1-ND
7 | 2 | C23, C24 | C_0603_10n_X7R_100V | KD_Capacitor:C_0603_10n_X7R_100V | KD_Capacitor:CAPC1608X90N |  | 10n | F | C1608X7R2A103K080AA | TDK Corporation | 0.05 | Digi-Key | 445-1304-1-ND
8 | 3 | D1, D6, D7 | Schottky_30V_1A_Toshiba_CUS10S30 | KD_Diode:Schottky_30V_1A_Toshiba_CUS10S30 | KD_Diode:D_SOD-323 | https://toshiba.semicon-storage.com/info/docget.jsp?did=14077&prodName=CUS10S30 | CUS10S30,H3F | F | CUS10S30,H3F | Toshiba Semiconductor and Storage | 0.2 | Digi-Key | CUS10S30H3FCT-ND
9 | 1 | D2 | TVS_12V_LF_SMAJ12CA | KD_Diode:TVS_12V_LF_SMAJ12CA | KD_Diode:DIOC530X280X230_SMA_A | https://media.digikey.com/pdf/Data%20Sheets/AVX%20PDFs/Transient%20Suppression%20Diodes.pdf | SMAJ12A | F | SMAJ12A | Littelfuse Inc. | 0.3 | Digi-Key | SMAJ12ALFCT-ND
10 | 1 | D3 | 0603_Green_Clear_LTST-C190KGKT | KD_Led:0603_Green_Clear_LTST-C190KGKT | KD_Diode:DIOC1608X70 | https://optoelectronics.liteon.com/upload/download/DS22-2000-074/LTST-C190KGKT.PDF | Green Clear | F | LTST-C190KGKT | Lite-On Inc. | 0.05 | Digi-Key | 160-1435-1-ND
11 | 1 | D4 | TVS_5V5_DRTR5V0U4S-7-M | KD_Diode:TVS_5V5_DRTR5V0U4S-7-M | KD_Package_TO_SOT_SMD:SOT-363_SC-70-6 | https://www.diodes.com/assets/Datasheets/DRTR5V0U4S.pdf | DRTR5V0U4S-7 | F | DRTR5V0U4S-7 | Diodes Incorporated | 0.30 | Digi-Key | DRTR5V0U4S-7DICT-ND
12 | 1 | D5 | 7seg_70mm_CA_Lumex_LDS-AD16RI | KD_Display:7seg_70mm_CA_Lumex_LDS-AD16RI | KD_Display:7seg_70mm_Kingbright_SC23-11SURKWA | datasheet | LDS-AD16RI | F | LDS-AD16RI | Lumex Opto/Components Inc. | 13 | Digi-Key | 67-1493-ND
13 | 1 | F1 | Fuse_1A_C1F_1 | KD_Devices_Other:Fuse_1A_C1F_1 | KD_Resistor:RESC3216X70N | https://belfuse.com/resources/datasheets/circuitprotection/ds-cp-c1f-series.pdf | Fuse 1 A | F | C1F 1 | Bel Fuse Inc. | 0.15 | Digi-Key | 507-1878-1-ND
14 | 1 | FB1 | Ferrite_250mA_Murata_BLM15HG102SN1D | KD_Inductor:Ferrite_250mA_Murata_BLM15HG102SN1D | KD_Inductor:INDC1005X55N | datasheet | BLM15HG102SN1D | F | BLM15HG102SN1D | Murata Electronics | 0.10 | Digi-Key | 490-3999-1-ND
15 | 5 | H1, H3, H4, H5, H6 | NPTH_3.2_M3_Clearance | KD_Mechanical_Mounting_Hole:NPTH_3.2_M3_Clearance | KD_Mechanical_Mounting_Hole:NPTH_3.2mm_M3_clearance |  | 3.2 mm hole | T | DNP | DNP | 0.00 | DNP | DNP
16 | 6 | J1, J2, J4, J5, J6, J7 | Con_Screw_1x04_691313510004 | KD_Connector_Screw:Con_Screw_1x04_691313510004 | KD_Connector_Screw:CON_508_1X04_691313510004_Mated | https://www.we-online.com/katalog/datasheet/6913135100xx.pdf | 1x04 | F | 691313510004 | Würth Elektronik | 0.3 | Digi-Key | 732-2072-ND
17 | 1 | J3 | DC_2.1_5.5_54-00286 | KD_Connector_Circular:DC_2.1_5.5_54-00286 | KD_Connector_Circular:CON_DC_2.1_5.5_Tensility_54-00286 | http://www.tensility.com/pdffiles/54-00286.pdf | 2.1 mm DC | F | 54-00286 | CUI Devices | 0.7 | Digi-Key | 839-54-00286-ND
18 | 1 | J8 | USB_B_V_Adam_USB-B-S-VT | KD_Connector_USB_HDMI_Etc:USB_B_V_Adam_USB-B-S-VT | KD_Connector_USB_HDMI_Etc:USB_B_Vertical_Adam_USB-B-S-VT | https://app.adam-tech.com/products/download/data_sheet/195855/usb-b-s-vt-data-sheet.pdf | USB Mini B | F | USB-B-S-VT | Adam Tech | 1 | Digi-Key | 2057-USB-B-S-VT-ND
19 | 1 | M1 | Knob_6mm_BL_RED_CLIFF_CL170842CR | KD_Mechanical:Knob_6mm_BL_RED_CLIFF_CL170842CR | KD_Mechanical:Knob_CLIFF_CL170842CR |  | CL170842CR | F | CL170842CR | CLIFF Electronic Components Ltd | 1 | Digi-Key | 3185-CL170842CR-ND
20 | 1 | Q1 | PMOS_30V_4A1_SIL3407-TP | KD_Transistor_FET:PMOS_30V_4A1_SIL3407-TP | KD_Package_TO_SOT_SMD:SOT95P280X120-6RN | https://www.mccsemi.com/pdf/Products/SIL3407(SOT23-6L).pdf | SIL3407-TP | F | SIL3407-TP | Micro Commercial Co | 0.4 | Digi-Key | 353-SIL3407-TPCT-ND
21 | 2 | R1, R22 | R_0805_DNP | KD_Resistor:R_0805_DNP | KD_Resistor:RESC2012X60N_DNP | https://www.seielect.com/catalog/sei-rmcf_rmcp.pdf | DNP | T | DNP | DNP | 0.00 | DNP | DNP
22 | 5 | R2, R4, R15, R26, R27 | R_0603_22k_1% | KD_Resistor:R_0603_22k_1% | KD_Resistor:RESC1608X55N | https://www.yageo.com/upload/media/product/productsearch/datasheet/rchip/PYu-RC_Group_51_RoHS_L_11.pdf | 22k | F | 311-22.0KHRCT-ND | YAGEO | 0.01 | Digi-Key | 311-22.0KHRCT-ND
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

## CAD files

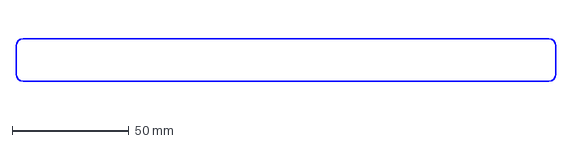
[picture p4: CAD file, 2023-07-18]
gear-display/Mechanics/RGB Diffuser/RGB Diffuser v5 - Body1.dxf
231.2 x 18.1 mm

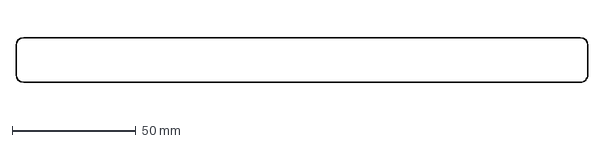
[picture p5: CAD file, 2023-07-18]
gear-display/Mechanics/RGB Diffuser/RGB diffuser.dxf
231.0 x 18.0 mm

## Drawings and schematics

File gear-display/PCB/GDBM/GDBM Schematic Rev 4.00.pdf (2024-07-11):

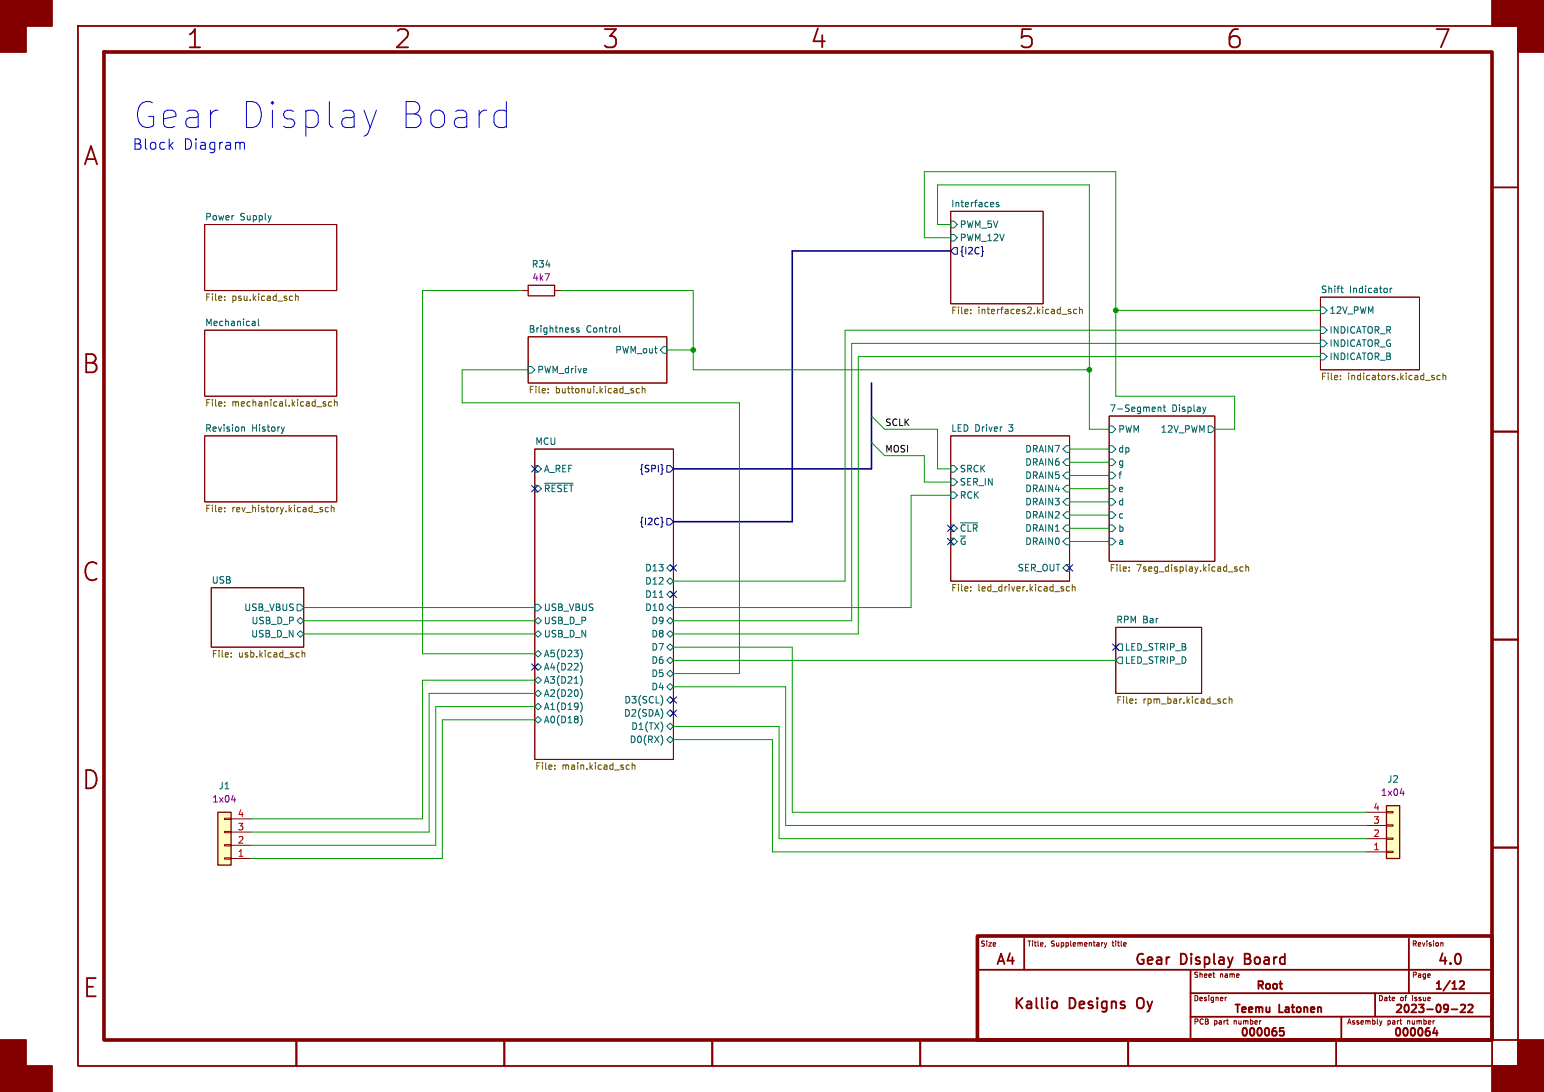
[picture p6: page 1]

1x04 MOSI SCLK Block Diagram

Shift Indicator File: indicators.kicad_sch

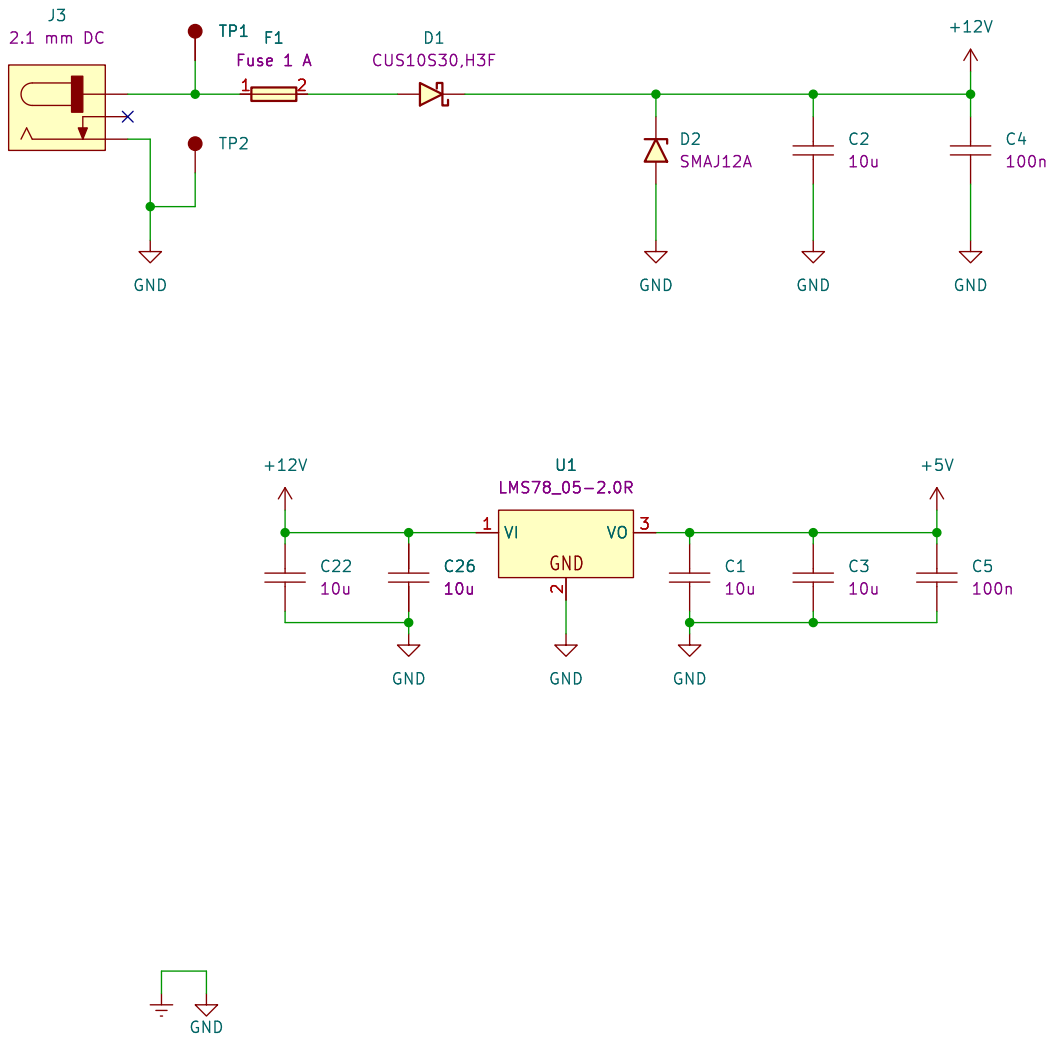
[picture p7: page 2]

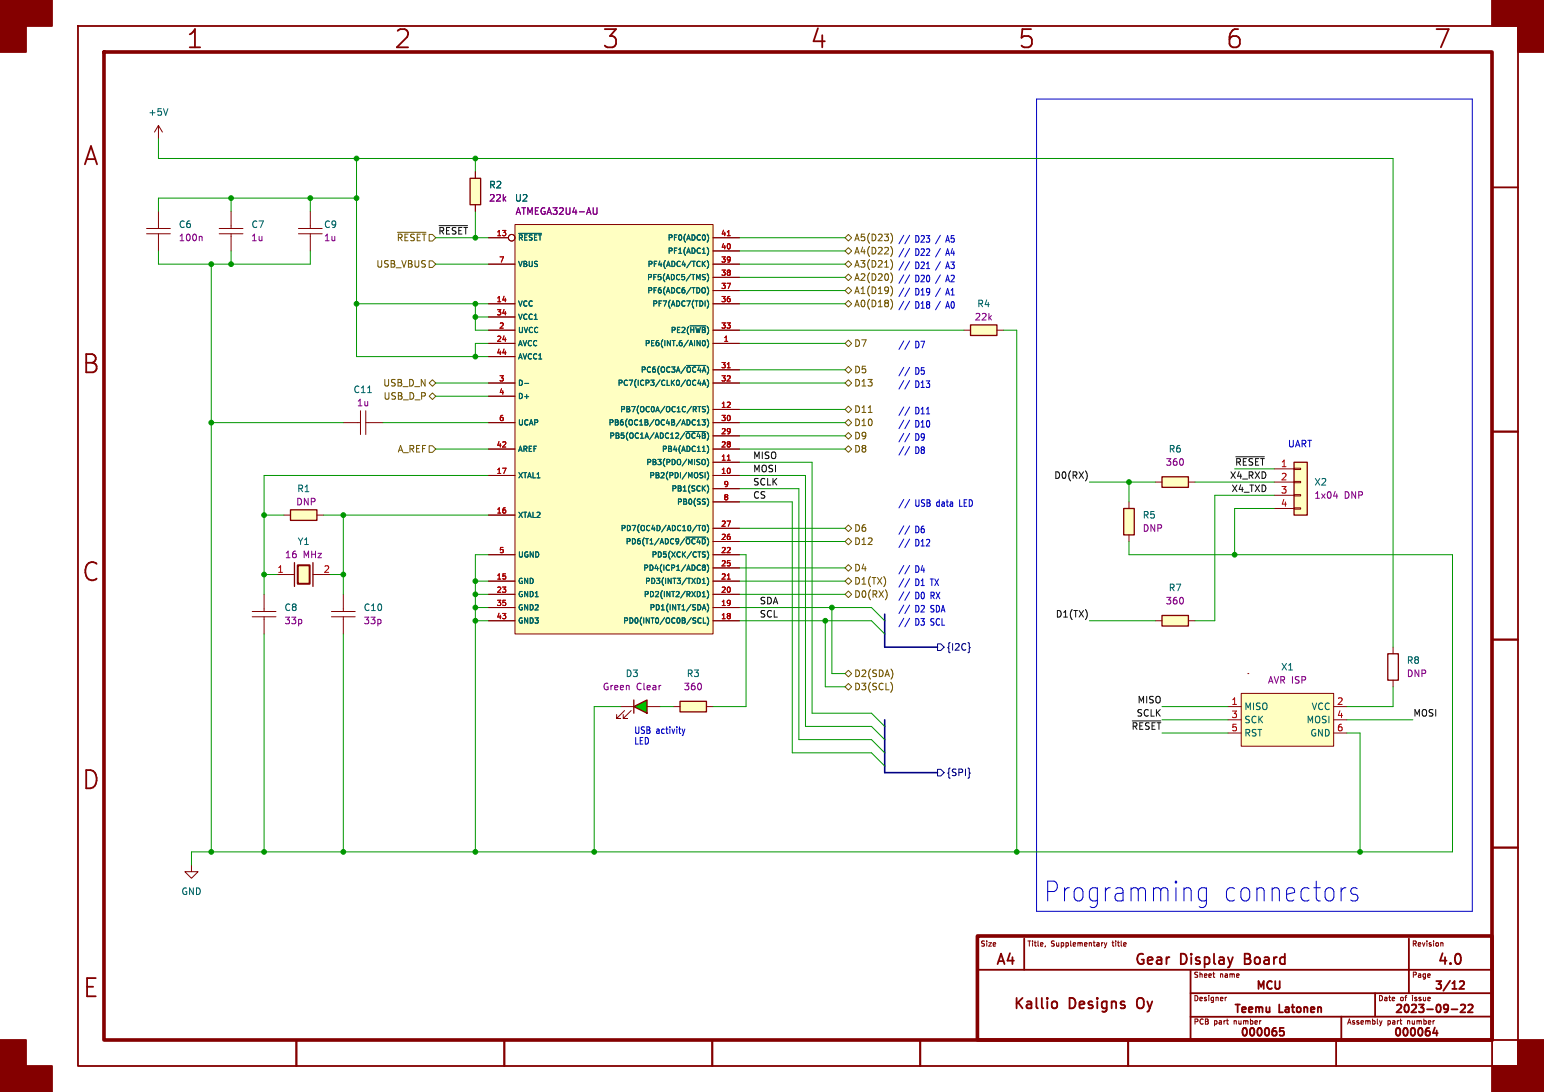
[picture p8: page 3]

D2(SDA) D11 D5 D10 D9 D8 D0(RX) MOSI SCL SDA

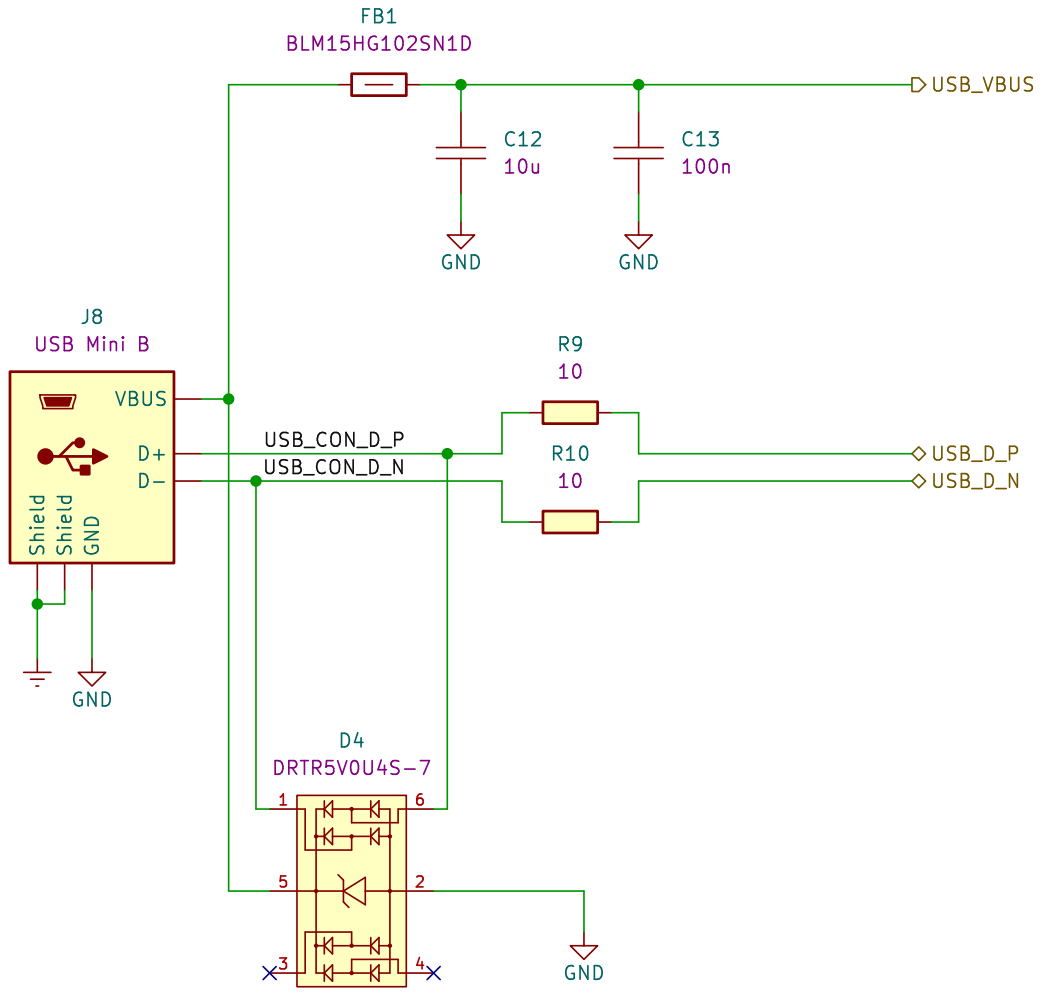
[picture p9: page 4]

10 VBUS D- D+ Shield Shield GND

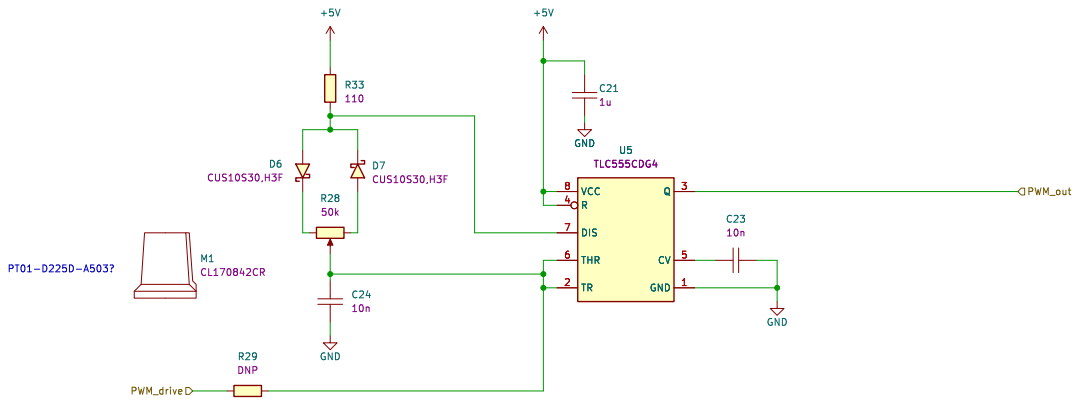
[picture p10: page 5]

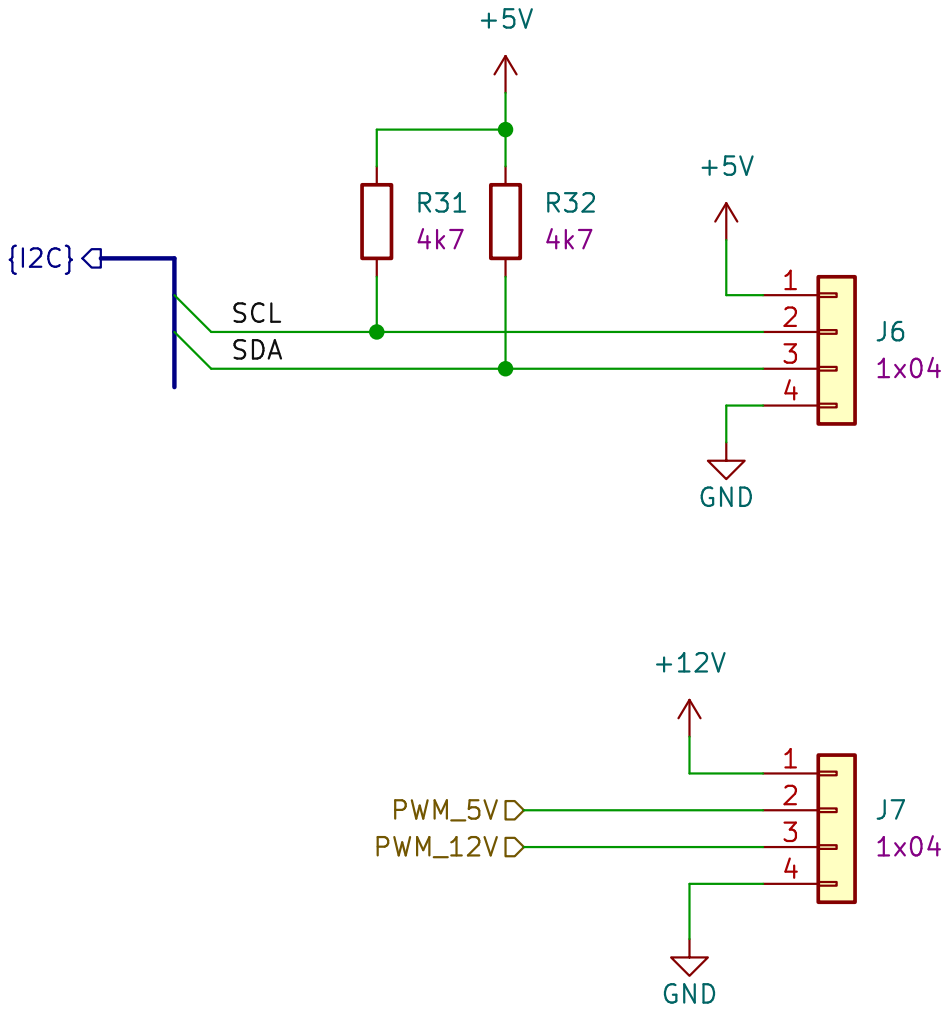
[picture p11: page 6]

Page 4.0

Sheet name

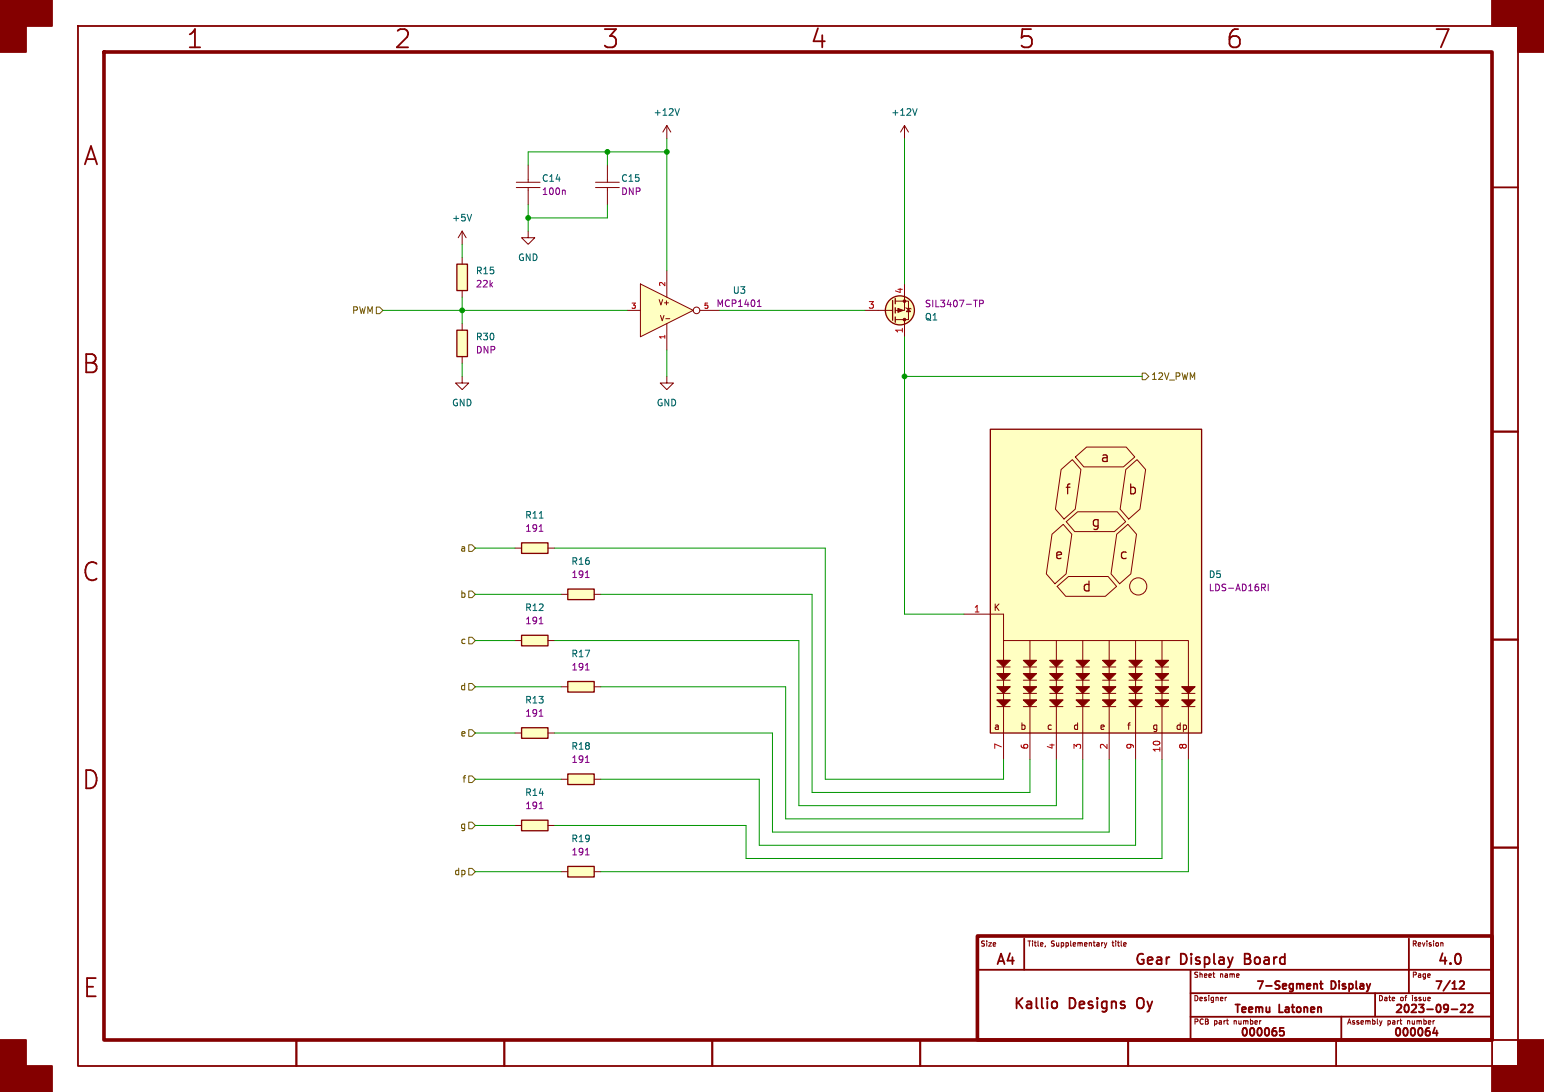
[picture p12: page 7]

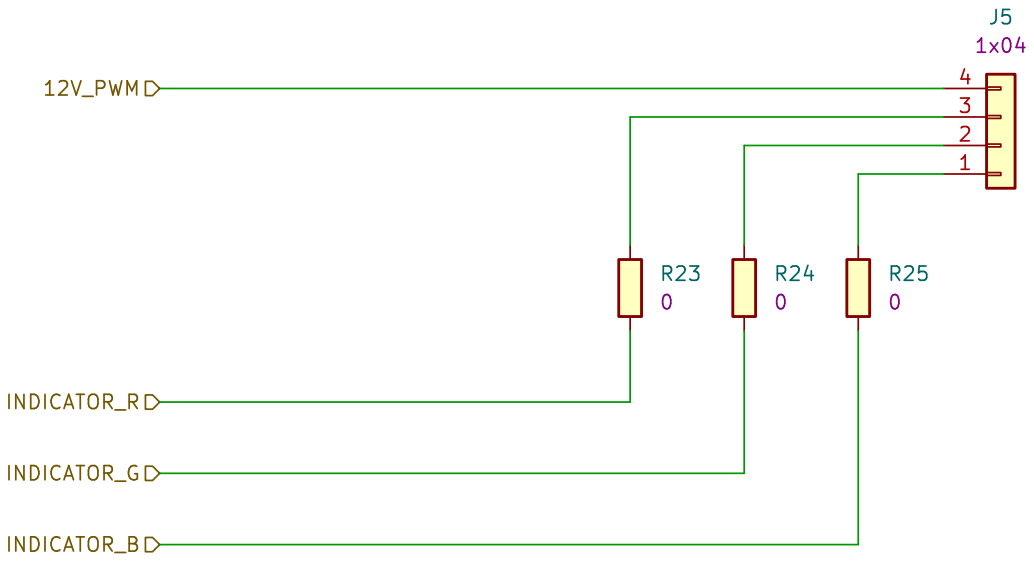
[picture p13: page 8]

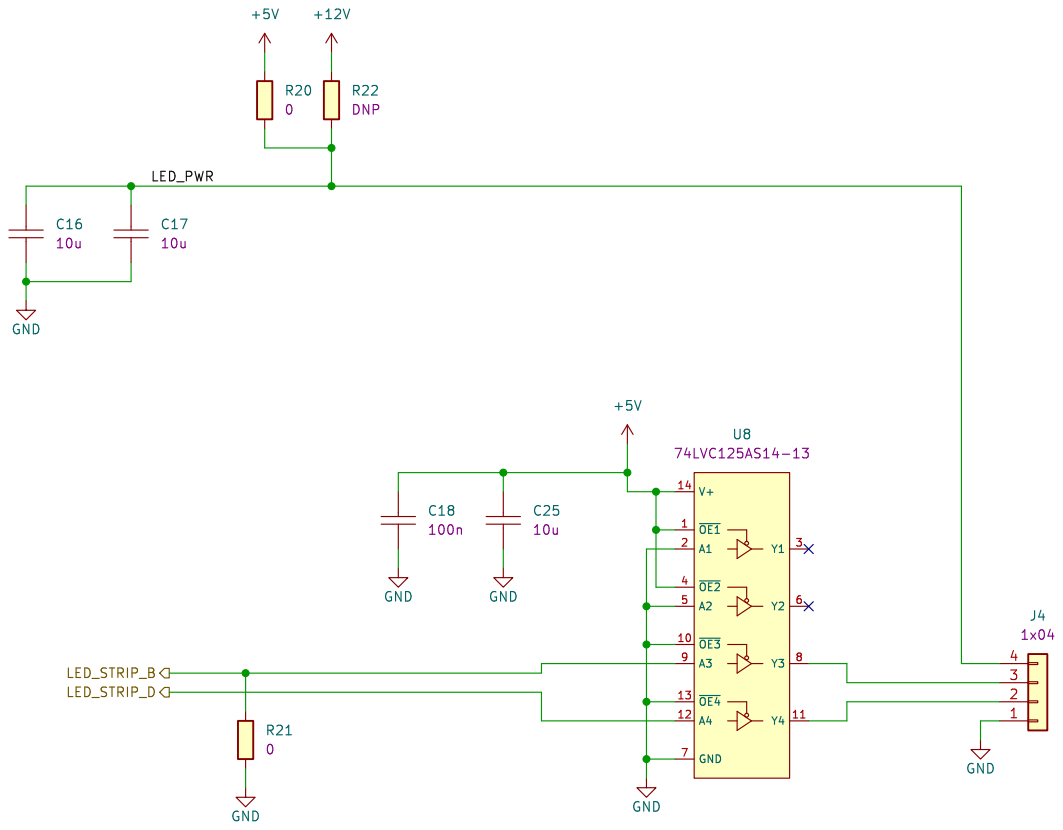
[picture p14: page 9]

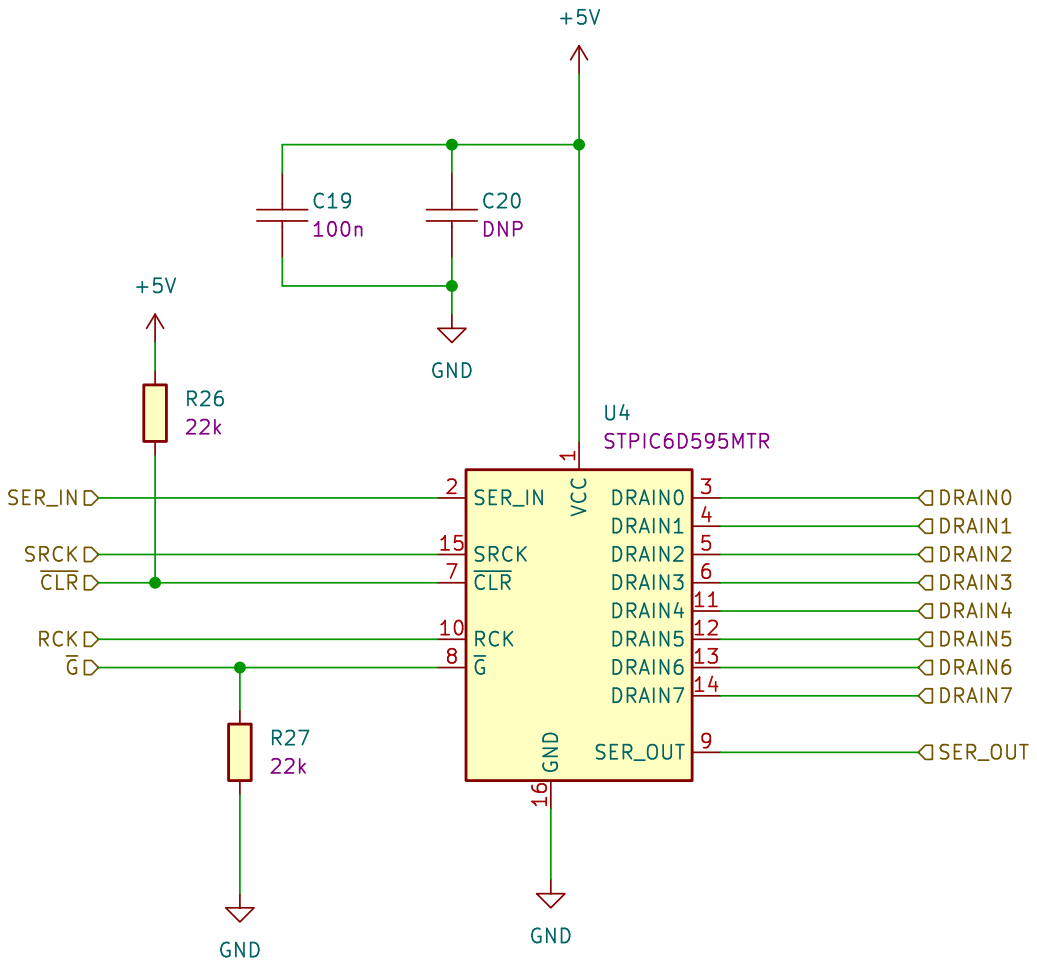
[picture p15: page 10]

1 RCK 10 DRAIN4 11 DRAIN5 12 DRAIN6 13 DRAIN7 14 SRCK 15 GND 16 SER_IN 2 DRAIN0 3 DRAIN1 4 DRAIN2 5 DRAIN3 6 ~{CLR} 7 ~{G} 8 SER_OUT 9 U4STPIC6D595MTR

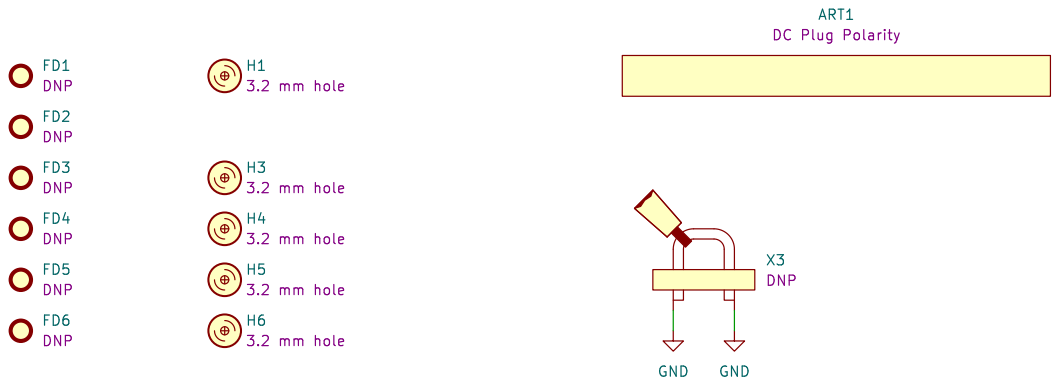
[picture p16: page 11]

ART1 DC Plug Polarity FD3 DNP
3.2 mm hole H1

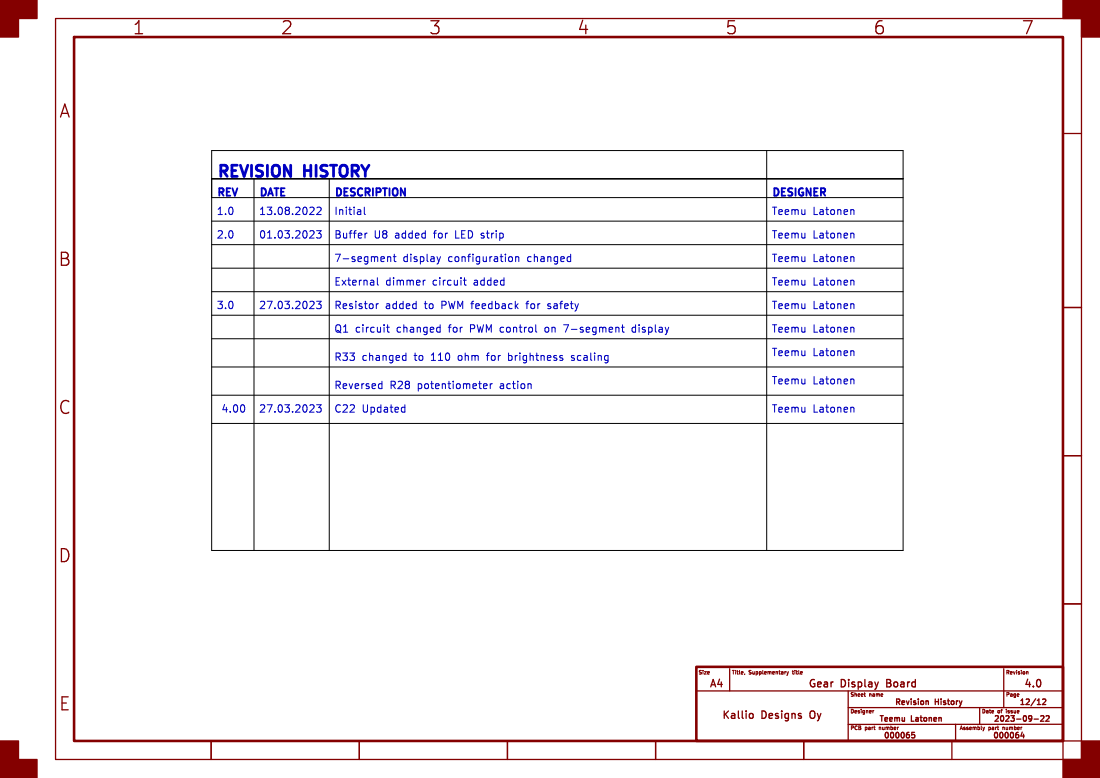
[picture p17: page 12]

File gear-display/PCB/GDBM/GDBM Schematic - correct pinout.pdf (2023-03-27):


1x04 SCLK MOSI Block Diagram

Power Supply File: psu.kicad_sch Mechanical File: mechanical.kicad_sch

File: main.kicad_sch Revision History File: rev_history.kicad_sch




100n VBUS D- D+ Shield Shield GND



Page 2.0

Sheet name





1 RCK 10 DRAIN4 11 DRAIN5 12 DRAIN6 13 DRAIN7 14 SRCK 15 GND 16 SER_IN 2 DRAIN0 3 DRAIN1 4 DRAIN2 5 DRAIN3 6 ~{CLR} 7 ~{G} 8 SER_OUT 9 U4STPIC6D595MTR


ART1 DC Plug Polarity FD4 DNP


1.0 | | 13.08.2022 | Teemu Latonen

Teemu Latonen

3.0 | 27.03.2023 | | | Teemu Latonen

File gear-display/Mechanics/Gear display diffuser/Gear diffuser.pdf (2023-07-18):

72


Dept. Technical reference Created by Approved by Title DWG No. Document type Document status Rev. Date of issue Sheet 31/03/2023 1/1 50

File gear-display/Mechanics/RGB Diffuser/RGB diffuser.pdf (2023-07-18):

18 5


1 A 2 3 4 5 6 7 8 1 2 3 4 5 6 7 8 FEDCB FEDCBA Dept. Technical reference Created by Approved by Title DWG No. Document type Document status Rev. Date of issue Sheet 31/03/2023 1/1 RGB Diffuser 231

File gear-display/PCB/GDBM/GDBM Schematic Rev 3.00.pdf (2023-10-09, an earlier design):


1x04 MOSI SCLK Gear Display Board

Shift Indicator File: indicators.kicad_sch Mechanical File: mechanical.kicad_sch




10 VBUS D- D+ Shield Shield GND



Page 3.0

Sheet name





1 RCK 10 DRAIN4 11 DRAIN5 12 DRAIN6 13 DRAIN7 14 SRCK 15 GND 16 SER_IN 2 DRAIN0 3 DRAIN1 4 DRAIN2 5 DRAIN3 6 ~{CLR} 7 ~{G} 8 SER_OUT 9 U4STPIC6D595MTR


ART1 DC Plug Polarity FD3 DNP
3.2 mm hole H1


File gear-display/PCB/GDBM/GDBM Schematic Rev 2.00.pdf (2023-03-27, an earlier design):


1x04 MOSI SCLK Block Diagram

Shift Indicator File: indicators.kicad_sch Mechanical File: mechanical.kicad_sch Power Supply File: psu.kicad_sch USB_D_P USB_D_N
File: usb.kicad_sch Revision History File: rev_history.kicad_sch
D2(SDA) MCU




VBUS D- D+ Shield Shield GND



Page 2.0

Sheet name





1 RCK 10 DRAIN4 11 DRAIN5 12 DRAIN6 13 DRAIN7 14 SRCK 15 GND 16 SER_IN 2 DRAIN0 3 DRAIN1 4 DRAIN2 5 DRAIN3 6 ~{CLR} 7 ~{G} 8 SER_OUT 9 U4STPIC6D595MTR


ART1 DC Plug Polarity FD3 DNP
3.2 mm hole H1


1.0 | | 13.08.2022 | Teemu Latonen

2.0 | 01.03.2023 | | | | | Teemu Latonen

Teemu Latonen

3.0 | 27.03.2023 | | | Teemu Latonen

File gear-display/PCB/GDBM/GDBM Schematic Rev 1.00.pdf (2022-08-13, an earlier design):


MCU:n signaalien kytkeminen
File: usb.kicad_sch Revision History
File: rev_history.kicad_sch POT_W

LED Driver 3 File: led_driver.kicad_sch Mechanical File: mechanical.kicad_sch USB_D_P USB_D_N

Brightness Control File: buttonui.kicad_sch

Page 1.0

Sheet name


A4 | | Page 1.0

Sheet name


Page 1.0

Sheet name


10 VBUSD- D+ Shield Shield GND

Page 1.0

Sheet name


A4 | | Page 1.0

Sheet name /Brightness Control/


Page 1.0

Sheet name


A4 | | Page 1.0

Sheet name


Page 1.0

Sheet name


Page 1.0

Sheet name


1 RCK 10 DRAIN4 11 DRAIN5 12 DRAIN6 13 DRAIN7 14 SRCK 15 GND 16 SER_IN 2 DRAIN0 3 DRAIN1 4 DRAIN2 5 DRAIN3 6 ~{CLR} 7 ~{G} 8 SER_OUT 9 U4STPIC6D595MTR GND

Page 1.0

Sheet name


ART1 DC Plug Polarity FD6 DNP
3.2 mm hole H1

Page 1.0

Sheet name


DESCRIPTION | DESIGNER

A4 | | Page 1.0

Sheet name /Revision History/

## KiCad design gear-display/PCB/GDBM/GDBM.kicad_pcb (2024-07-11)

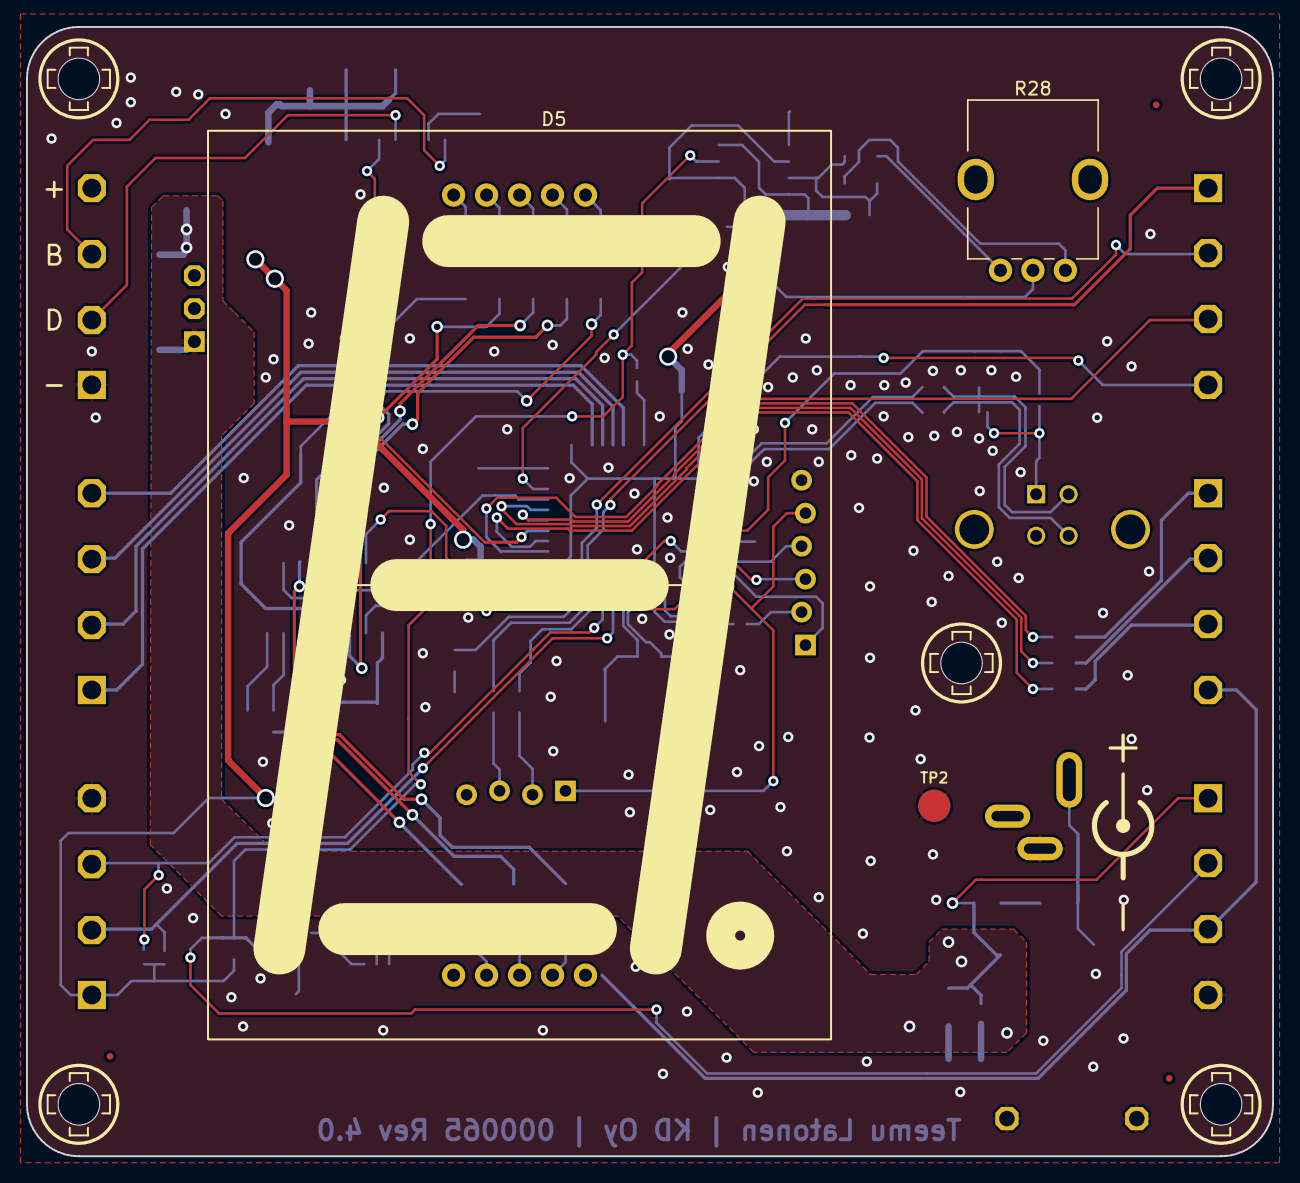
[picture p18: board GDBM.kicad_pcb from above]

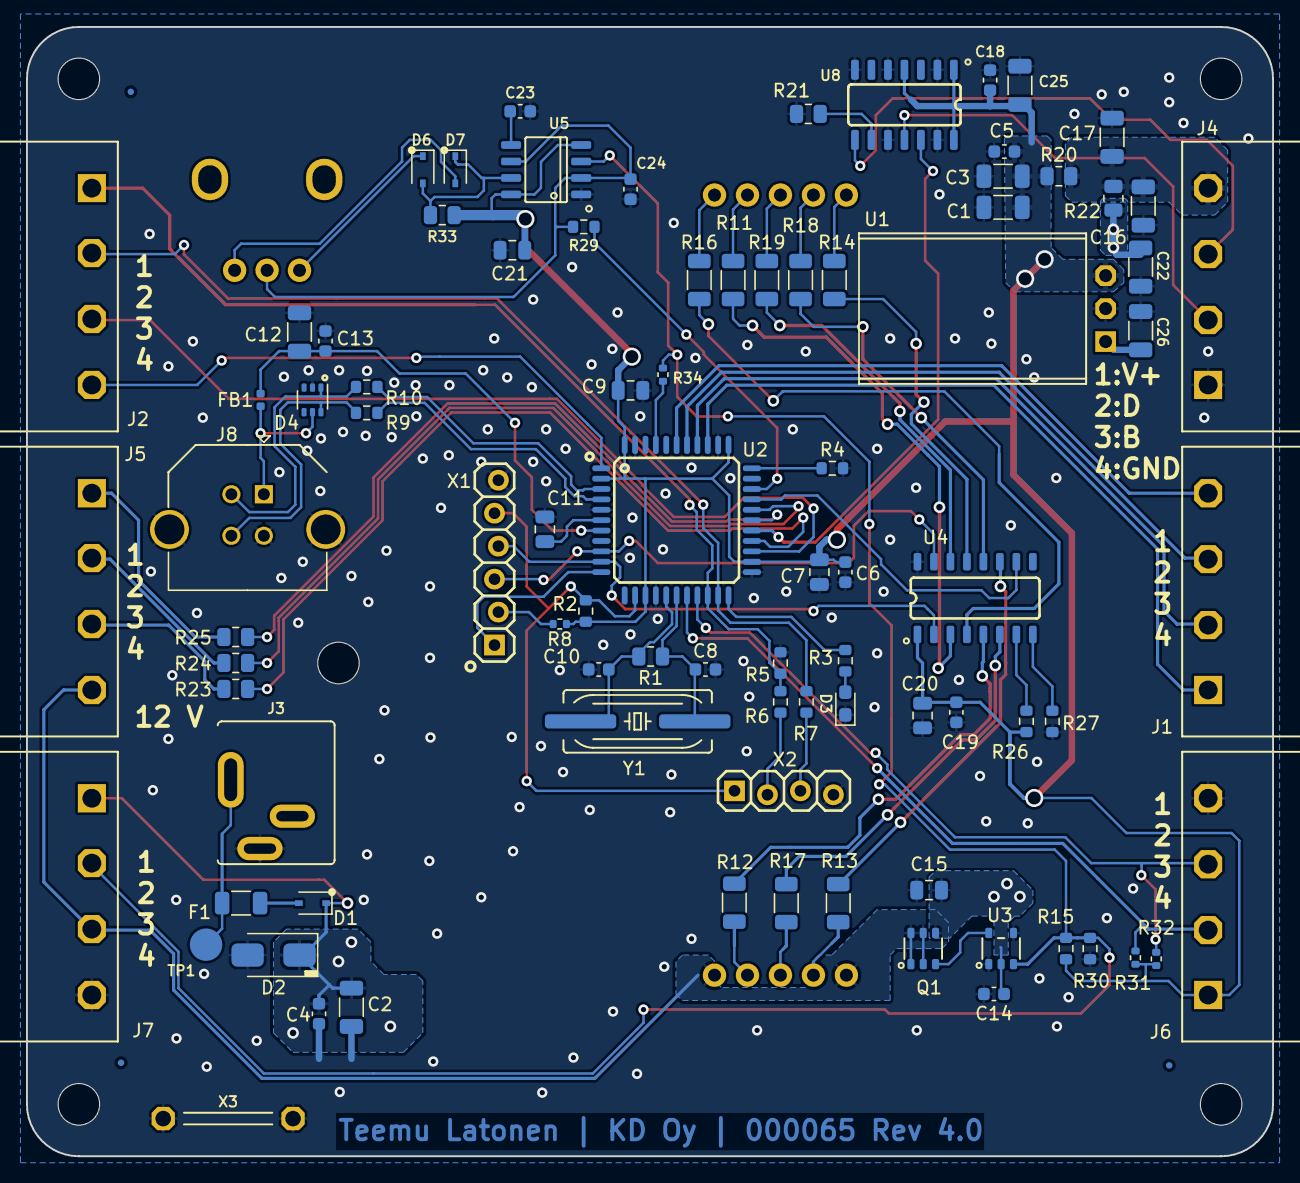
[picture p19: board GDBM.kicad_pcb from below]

Board: 2 copper layers, 96.0 x 87.0 mm, 103 parts (90 on the bottom side), 74 nets.

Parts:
ART1: Artwork_DC_Plug_Polarity; ART_DC_POLARITY
C1, C2, C3, C12, C16, C17, C22, C25, C26: 10u; CAPC3216X150N
C4, C5, C6, C13, C14, C18, C19: 100n; CAPC1608X90N
C7, C9, C11, C21: 1u; CAPC2012X135N
C8, C10: 33p; CAPC1608X90N
C15, C20: 0805; CAPC2012X135N_DNP
C23, C24: 10n; CAPC1608X90N
D1, D6, D7: Schottky_30V_1A_Toshiba_CUS10S30; D_SOD-323
D2: TVS_12V_LF_SMAJ12CA; DIOC530X280X230_SMA_A
D3: 0603_Green_Clear_LTST-C190KGKT; LEDM1608X70M
D4: TVS_5V5_DRTR5V0U4S-7-M; SOT-363_SC-70-6
D5: 7seg_70mm_CA_Lumex_LDS-AD16RI; 7seg_70mm_Kingbright_SC23-11SURKWA
F1: Fuse_1A_C1F_1; RESC3216X70N
FB1: Ferrite_250mA_Murata_BLM15HG102SN1D; INDC1005X55N
FD1, FD2, FD3, FD4, FD5, FD6: Fiducial 0.5 mm; Fiducial_0.5mm_Mask1mm
H1, H3, H4, H5, H6: NPTH 3.2 M3 Clearance; NPTH_3.2mm_M3_clearance
J1, J2, J4, J5, J6, J7: 1x04; CON_508_1X04_691313510004_Mated
J3: DC_2.1_5.5_54-00286; CON_DC_2.1_5.5_Tensility_54-00286
J8: USB Mini B; USB_B_Vertical_Adam_USB-B-S-VT
M1: Knob_6mm_BL_RED_CLIFF_CL170842CR; Knob_CLIFF_CL170842CR
Q1: PMOS_30V_4A1_SIL3407-TP; SOT95P280X120-6RN
R1, R22: DNP; RESC2012X60N_DNP
R2, R4, R15, R26, R27: R_0603_22k_1%; RESC1608X55N
R3, R6, R7: R_0603_360_1%; RESC1608X55N
R5, R29, R30: R_0603_DNP; RESC1608X55N_DNP
R8: R_0402_DNP; RESC1005X40N
R9, R10: R_0603_10_5%; RESC1608X55N
R11, R12, R13, R14, R16, R17, R18, R19: R_1206_191_1%; RESC3216X70N
R20, R21, R23, R24, R25: 0; RESC2012X60N
R28: PT01-D225D-A503; Potentiometer_CUI_PT01-DX20K2-XXXX
R31, R32, R34: 4k7; RESC1005X40N
R33: R_0805_110_5%; RESC2012X60N
TP1, TP2: TestPoint_2.5mm_Round; TestPoint_Pad_D2.5mm
U1: DC_DC_5V_2A0_GAPTEC_OKI-78SR-5_H; DC_DC_GAPTEC_OKI-78SR-5_H
U2: ATmega32U4-AU; QFP80P1200X1200X120-44R_N
U3: MCP1401; SOT95P280X145-5N
U4: Shift_register_OC_8bit_STPIC6D595MTR; SOIC127P640X200-16N
U5: Timer_Oscillator_TLC555CDG4; SOIC127P600X175-8
U8: Buffer_74LVC125AS14-13_DIODES; SOIC127P600X175-14N
X1: Programming_AVR_ISP_Staggered_Holes; CON_PINHD_1X06_TH_OFFSET
X2: CON_1x04_TH_staggered; CON_PINHD_1X04_TH_OFFSET
X3: GND Hook; GND_HOOK_M
Y1: 16 MHz; OSC_CRYSTAL_HC49_US_N

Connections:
+5V: C1.1, C3.1, C5.1, C6.1, C7.2, C9.1, C18.1, C19.1, C20.1, C21.1, C25.1, J6.1, R2.1, R8.1, R15.1, R20.1, R26.1, R31.1, R32.1, R33.1, U1.3 (VO), U2.2 (UVCC), U2.14 (VCC), U2.24 (AVCC), U2.34 (VCC1), U2.44 (AVCC1), U4.1 (VCC), U5.4 (R), U5.8 (VCC), U8.1 (~OE1), U8.4 (~OE2), U8.14 (V+)
+12V: C2.1, C4.1, C14.1, C15.1, C22.1, C26.1, D1.1 (K), D2.1 (K), J7.1, Q1.4 (S), R22.1, U1.1 (VI), U3.2 (VCC)
/7-Segment Display/12V_PWM: D5.1 (K), D5.5 (C), J5.4, J7.3, Q1.1 (D), Q1.2 (D), Q1.5 (D), Q1.6 (D)
/7-Segment Display/PWM: J7.2, R15.2, R30.1, R34.2, U3.3 (IN), U5.3 (Q)
/7-Segment Display/a: R11.1, U4.3 (DRAIN0)
/7-Segment Display/b: R16.1, U4.4 (DRAIN1)
/7-Segment Display/c: R12.1, U4.5 (DRAIN2)
/7-Segment Display/d: R17.1, U4.6 (DRAIN3)
/7-Segment Display/dp: R19.1, U4.14 (DRAIN7)
/7-Segment Display/e: R13.1, U4.11 (DRAIN4)
/7-Segment Display/f: R18.1, U4.12 (DRAIN5)
/7-Segment Display/g: R14.1, U4.13 (DRAIN6)
/Brightness Control/PWM_drive: R29.1, U2.31 (PC6(OC3A/~OC4A))
/Interfaces/SCL: J6.2, R31.2, U2.18 (PD0(INT0/OC0B/SCL))
/Interfaces/SDA: J6.3, R32.2, U2.19 (PD1(INT1/SDA))
/LED Driver 3/RCK: U2.30 (PB6(OC1B/OC4B/ADC13)), U4.10 (RCK)
/LED Driver 3/~CLR: R26.2, U4.7 (~CLR)
/LED Driver 3/~G: R27.1, U4.8 (~G)
/MCU/A0(D18): J1.1, U2.36 (PF7(ADC7(TDI))
/MCU/A1(D19): J1.2, U2.37 (PF6(ADC6/TDO))
/MCU/A2(D20): J1.3, U2.38 (PF5(ADC5/TMS))
/MCU/A3(D21): J1.4, U2.39 (PF4(ADC4/TCK))
/MCU/A5(D23): R34.1, U2.41 (PF0(ADC0))
/MCU/D0(RX): J2.1, R5.2, R6.1, U2.20 (PD2(INT2/RXD1))
/MCU/D1(TX): J2.2, R7.1, U2.21 (PD3(INT3/TXD1))
/MCU/D4: J2.3, U2.25 (PD4(ICP1/ADC8))
/MCU/D6: U2.27 (PD7(OC4D/ADC10/T0)), U8.12 (A4)
/MCU/D7: J2.4, U2.1 (PE6(INT.6/AIN0))
/MCU/D8: R25.2, U2.28 (PB4(ADC11))
/MCU/D9: R24.2, U2.29 (PB5(OC1A/ADC12/~OC4B))
/MCU/D12: R23.2, U2.26 (PD6(T1/ADC9/~OC4D))
/MCU/MISO: U2.11 (PB3(PDO/MISO)), X1.1 (MISO)
/MCU/MOSI: U2.10 (PB2(PDI/MOSI)), U4.2 (SER_IN), X1.4 (MOSI)
/MCU/SCLK: U2.9 (PB1(SCK)), U4.15 (SRCK), X1.3 (SCK)
/MCU/USB_D_N: R10.2, U2.3 (D-)
/MCU/USB_D_P: R9.2, U2.4 (D+)
/MCU/USB_VBUS: C12.1, C13.1, FB1.2, U2.7 (VBUS)
/MCU/X4_RXD: R6.2, X2.2
/MCU/X4_TXD: R7.2, X2.3
/MCU/~RESET: R2.2, U2.13 (~RESET), X1.5 (RST), X2.1
/RPM Bar/LED_PWR: C16.1, C17.1, J4.4, R20.2, R22.2
/RPM Bar/LED_STRIP_B: R21.1, U8.9 (A3)
/USB/USB_CON_D_N: D4.1, J8.2 (D-), R10.1
/USB/USB_CON_D_P: D4.6, J8.3 (D+), R9.1
Earth: C1.2, C2.2, C3.2, C4.2, C5.2, C6.2, C7.1, C8.2, C9.2, C10.2, C11.1, C12.2, C13.2, C14.2, C15.2, C16.2, C17.2, C18.2, C19.2, C20.2, C21.2, C22.2, C23.2, C24.1, C25.2, C26.2, D2.2 (A), D3.1 (K), D4.2 (V-), J3.B (SLEEVE), J4.1, J6.4, J7.4, J8.4 (GND), J8.H1 (Shield), J8.H2 (Shield), R4.2, R5.1, R21.2, R27.2, R30.2, TP2.1, U1.2 (GND), U2.5 (UGND), U2.15 (GND), U2.23 (GND1), U2.35 (GND2), U2.43 (GND3), U3.1 (GND), U3.4 (GND), U4.16 (GND), U5.1 (GND), U8.2 (A1), U8.5 (A2), U8.7 (GND), U8.10 (~OE3), U8.13 (~OE4), X1.6 (GND), X2.4, X3.1, X3.2 (Pin_1)
unnamed: D1.2 (A), F1.2
unnamed: D3.2 (A), R3.1
unnamed: D4.5 (V+), FB1.1, J8.1 (VBUS)
unnamed: D5.7 (Aa), R11.2
unnamed: D5.6 (Ab), R16.2
unnamed: D5.4 (Ac), R12.2
unnamed: D5.3 (Ad), R17.2
unnamed: D5.8 (Adp), R19.2
unnamed: D5.2 (Ae), R13.2
unnamed: D5.9 (Af), R18.2
unnamed: D5.10 (Ag), R14.2
unnamed: D6.2 (A), D7.1 (K), R33.2, U5.7 (DIS)
unnamed: D6.1 (K), R28.3
unnamed: D7.2 (A), R28.1
unnamed: F1.1, J3.A (CENTER), TP1.1
unnamed: J4.2, U8.11 (Y4)
unnamed: J4.3, U8.8 (Y3)
unnamed: J5.1, R25.1
unnamed: J5.2, R24.1
unnamed: J5.3, R23.1
unnamed: Q1.3 (G), U3.5 (OUT)
unnamed: R3.2, U2.22 (PD5(XCK/CTS))
unnamed: R4.1, U2.33 (PE2(~HWB))
unnamed: C11.2, U2.6 (UCAP)
unnamed: C8.1, R1.1, U2.17 (XTAL1), Y1.1
unnamed: C10.1, R1.2, U2.16 (XTAL2), Y1.2
unnamed: C23.1, U5.5 (CV)
unnamed: C24.2, R28.2, R29.2, U5.2 (TR), U5.6 (THR)
unnamed: R8.2, X1.2 (VCC)

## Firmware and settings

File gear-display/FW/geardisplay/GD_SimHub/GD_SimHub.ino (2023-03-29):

// J revision sketch
#define VERSION 'j'

// ----------------------------------------------------- PLEASE USE SETUP ASSISTANT AVAILABLE IN SUB FOLDER !!!! -------------------------------------------
// ----------------------------------------------------- PLEASE USE SETUP ASSISTANT AVAILABLE IN SUB FOLDER !!!! -------------------------------------------
// ----------------------------------------------------- PLEASE USE SETUP ASSISTANT AVAILABLE IN SUB FOLDER !!!! -------------------------------------------
// ----------------------------------------------------- PLEASE USE SETUP ASSISTANT AVAILABLE IN SUB FOLDER !!!! -------------------------------------------
// ----------------------------------------------------- PLEASE USE SETUP ASSISTANT AVAILABLE IN SUB FOLDER !!!! -------------------------------------------
// ----------------------------------------------------- PLEASE USE SETUP ASSISTANT AVAILABLE IN SUB FOLDER !!!! -------------------------------------------
// ----------------------------------------------------- PLEASE USE SETUP ASSISTANT AVAILABLE IN SUB FOLDER !!!! -------------------------------------------
// ----------------------------------------------------- PLEASE USE SETUP ASSISTANT AVAILABLE IN SUB FOLDER !!!! -------------------------------------------
// ----------------------------------------------------- PLEASE USE SETUP ASSISTANT AVAILABLE IN SUB FOLDER !!!! -------------------------------------------
// ----------------------------------------------------- PLEASE USE SETUP ASSISTANT AVAILABLE IN SUB FOLDER !!!! -------------------------------------------
// ----------------------------------------------------- PLEASE USE SETUP ASSISTANT AVAILABLE IN SUB FOLDER !!!! -------------------------------------------
// ----------------------------------------------------- PLEASE USE SETUP ASSISTANT AVAILABLE IN SUB FOLDER !!!! -------------------------------------------

//#define INCLUDE_TM1638                      //{"Name":"INCLUDE_TM1638","Type":"autodefine","Condition":"[TM1638_ENABLEDMODULES]>0"}
//#define INCLUDE_WS2801                      //{"Name":"INCLUDE_WS2801","Type":"autodefine","Condition":"[WS2801_RGBLEDCOUNT]>0"}
#define INCLUDE_WS2812B                     //{"Name":"INCLUDE_WS2812B","Type":"autodefine","Condition":"[WS2812B_RGBLEDCOUNT]>0"}
//#define INCLUDE_PL9823                      //{"Name":"INCLUDE_PL9823","Type":"autodefine","Condition":"[PL9823_RGBLEDCOUNT]>0"}
//#define INCLUDE_WS2812B_MATRIX              //{"Name":"INCLUDE_WS2812B_MATRIX","Type":"autodefine","Condition":"[WS2812B_MATRIX_ENABLED]>0"}
//#define INCLUDE_LEDBACKPACK                 //{"Name":"INCLUDE_LEDBACKPACK","Type":"autodefine","Condition":"[ENABLE_ADA_HT16K33_7SEGMENTS]>0 || [ENABLE_ADA_HT16K33_BiColorMatrix]>0"}
//#define INCLUDE_TM1637                      //{"Name":"INCLUDE_TM1637","Type":"autodefine","Condition":"[TM1637_ENABLEDMODULES]>0"}
//#define INCLUDE_TM1637_6D                   //{"Name":"INCLUDE_TM1637_6D","Type":"autodefine","Condition":"[TM1637_6D_ENABLEDMODULES]>0"}
//#define INCLUDE_I2CLCD                      //{"Name":"INCLUDE_I2CLCD","Type":"autodefine","Condition":"[I2CLCD_enabled]>0"}
//#define INCLUDE_NOKIALCD                    //{"Name":"INCLUDE_NOKIALCD","Type":"autodefine","Condition":"[ENABLED_NOKIALCD]>0"}
//#define INCLUDE_OLED                        //{"Name":"INCLUDE_OLED","Type":"autodefine","Condition":"[ENABLED_OLEDLCD]>0"}
//#define INCLUDE_MAX7221MATRIX               //{"Name":"INCLUDE_MAX7221MATRIX","Type":"autodefine","Condition":"[MAX7221_MATRIX_ENABLED]>0"}
//#define INCLUDE_HT16K33_SINGLECOLORMATRIX   //{"Name":"INCLUDE_HT16K33_SINGLECOLORMATRIX","Type":"autodefine","Condition":"[ENABLE_ADA_HT16K33_SingleColorMatrix]>0"}
//#define INCLUDE_74HC595_GEAR_DISPLAY        //{"Name":"INCLUDE_74HC595_GEAR_DISPLAY","Type":"autodefine","Condition":"[ENABLE_74HC595_GEAR_DISPLAY]>0"}
//#define INCLUDE_MAX7221_MODULES             //{"Name":"INCLUDE_MAX7221_MODULES","Type":"autodefine","Condition":"[MAX7221_ENABLEDMODULES]>0"}
#define INCLUDE_6c595_GEAR_DISPLAY          //{"Name":"INCLUDE_6c595_GEAR_DISPLAY ","Type":"autodefine","Condition":"[ENABLE_6C595_GEAR_DISPLAY]>0"}
//#define INCLUDE_TACHOMETER                  //{"Name":"INCLUDE_TACHOMETER ","Type":"autodefine","Condition":"[ENABLE_TACHOMETER]>0"}
//#define INCLUDE_BOOSTGAUGE                  //{"Name":"INCLUDE_BOOSTGAUGE ","Type":"autodefine","Condition":"[ENABLE_BOOSTGAUGE]>0"}
//#define INCLUDE_SPEEDOGAUGE                 //{"Name":"INCLUDE_SPEEDOGAUGE","Type":"autodefine","Condition":"[ENABLE_SPEEDOGAUGE]>0"}
//#define INCLUDE_FUELGAUGE                   //{"Name":"INCLUDE_FUELGAUGE ","Type":"autodefine","Condition":"[ENABLE_FUELGAUGE]>0"}
//#define INCLUDE_TEMPGAUGE                   //{"Name":"INCLUDE_TEMPGAUGE ","Type":"autodefine","Condition":"[ENABLE_TEMPGAUGE]>0"}
//#define INCLUDE_CONSGAUGE                   //{"Name":"INCLUDE_CONSGAUGE ","Type":"autodefine","Condition":"[ENABLE_CONSGAUGE]>0"}
//#define INCLUDE_SHAKEITADASHIELD            //{"Name":"INCLUDE_SHAKEITADASHIELD ","Type":"autodefine","Condition":"[ADAMOTORS_SHIELDSCOUNT]>0"}
//#define INCLUDE_SHAKEITDKSHIELD             //{"Name":"INCLUDE_SHAKEITDKSHIELD ","Type":"autodefine","Condition":"[DKMOTOR_SHIELDSCOUNT]>0"}
//#define INCLUDE_SHAKEITL298N                //{"Name":"INCLUDE_SHAKEITL298N","Type":"autodefine","Condition":"[L98NMOTORS_ENABLED]>0"}
//#define INCLUDE_SHAKEITMOTOMONSTER          //{"Name":"INCLUDE_SHAKEITMOTOMONSTER","Type":"autodefine","Condition":"[MOTOMONSTER_ENABLED]>0"}
//#define INCLUDE_SHAKEIDUALVNH5019           //{"Name":"INCLUDE_SHAKEIDUALVNH5019","Type":"autodefine","Condition":"[DUALVNH5019_ENABLED]>0"}

//#define INCLUDE_SHAKEITPWM                  //{"Name":"INCLUDE_SHAKEITPWM","Type":"autodefine","Condition":"[SHAKEITPWM_ENABLED_MOTORS]>0"}
//#define INCLUDE_SHAKEITPWMFANS              //{"Name":"INCLUDE_SHAKEITPWMFANS","Type":"autodefine","Condition":"[SHAKEITPWMFANS_ENABLED_MOTORS]>0"}
#if defined (__AVR_ATmega32U4__)
//#define INCLUDE_GAMEPAD                     //{"Name":"INCLUDE_GAMEPAD","Type":"autodefine","Condition":"[ENABLE_MICRO_GAMEPAD]>0"}
#endif
//#define INCLUDE_GAMEPADAXIS                 //{"Name":"INCLUDE_GAMEPADAXIS","Type":"autodefine","Condition":"[GAMEPAD_AXIS_01_ENABLED]>0 || [GAMEPAD_AXIS_02_ENABLED]>0 || [GAMEPAD_AXIS_03_ENABLED]>0"}

#ifdef INCLUDE_GAMEPADAXIS
#ifndef  INCLUDE_GAMEPAD
#error Gamepad option must be enabled in order to use analog axis.
#endif // ! INCLUDE_GAMEPAD
#endif

//#define INCLUDE_ENCODERS                    //{"Name":"INCLUDE_ENCODERS","Type":"autodefine","Condition":"[ENABLED_ENCODERS_COUNT]>0","IsInput":true}
//#define INCLUDE_BUTTONS                     //{"Name":"INCLUDE_BUTTONS","Type":"autodefine","Condition":"[ENABLED_BUTTONS_COUNT]>0","IsInput":true}
//#define INCLUDE_BUTTONMATRIX                //{"Name":"INCLUDE_BUTTONMATRIX","Type":"autodefine","Condition":"[ENABLED_BUTTONMATRIX]>0","IsInput":true}
//#define INCLUDE_DM163_MATRIX                //{"Name":"INCLUDE_DM163_MATRIX","Type":"autodefine","Condition":"[DM163_MATRIX_ENABLED]>0"}
//#define INCLUDE_SUNFOUNDERSH104P_MATRIX     //{"Name":"INCLUDE_SUNFOUNDERSH104P_MATRIX","Type":"autodefine","Condition":"[SUNFOUNDERSH104P_MATRIX_ENABLED]>0"}

#include <avr/pgmspace.h>
#include <EEPROM.h>
#include <SPI.h>
#include "Arduino.h"
#include <avr/pgmspace.h>
#include <Wire.h>
#include "Adafruit_GFX.h"
#include "FlowSerialRead.h"
#include "setPwmFrequency.h"
#include "SHDebouncer.h"
#include "SHButton.h"

// ----------------------------------------------------- HW SETTINGS, PLEASE REVIEW ALL -------------------------------------------
#define DEVICE_NAME "SimHub Dash" //{"Group":"General","Name":"DEVICE_NAME","Title":"Device name,\r\n make sure to use a unique name when using multiple arduinos","DefaultValue":"SimHub Dash","Type":"string","Template":"#define DEVICE_NAME \"{0}\""}
#define DEVICE_UNIQUE_ID "9b3ba899-ddc9-4e9d-94e9-1ad03e9ee848" //{"UniqueId":"9b3ba899-ddc9-4e9d-94e9-1ad03e9ee848","Name":"DEVICE_UNIQUE_ID","Type":"uniqueid"}

#define ENABLE_MICRO_GAMEPAD 0           //{"Group":"GAMEPAD","Name":"ENABLE_MICRO_GAMEPAD","Title":"Enable arduino micro gamepad output for all the activated buttons/encoders","DefaultValue":"0","Type":"bool"}
#define MICRO_GAMEPAD_ENCODERPRESSTIME 50 //{"Name":"MICRO_GAMEPAD_ENCODERPRESSTIME","Title":"Define how long (in milliseconds) the encoder related button will be hold after an encoder movement","DefaultValue":"50","Type":"int","Condition":"ENABLE_MICRO_GAMEPAD>0","Max":100}

// -------------------------------------------------------------------------------------------------------
// TM1638 Modules ----------------------------------------------------------------------------------------
// http://www.dx.com/p/jy-mcu-8x-green-light-digital-tube-8x-key-8x-double-color-led-module-104329
// https://www.fasttech.com/products/0/10006503/1497600-jy-mcu-8x-digital-tube-red-led-module
// -------------------------------------------------------------------------------------------------------
// Number of Connected TM1638/1639 modules
// 0 disabled, > 0 enabled
#define TM1638_ENABLEDMODULES 0 //{"Group":"TM1638 7 Segments Modules","Name":"TM1638_ENABLEDMODULES","Title":"TM1638 modules connected","DefaultValue":"0","Type":"int","Max":6}
#ifdef INCLUDE_TM1638
#define TM1638_SWAPLEDCOLORS 0  //{"Name":"TM1638_SWAPLEDCOLORS","Title":"Reverse Red and green colors ","DefaultValue":"0","Type":"bool","Condition":"TM1638_ENABLEDMODULES > 0"}
#define TM1638_DIO 8            //{"Name":"TM1638_DIO","Title":"Common data (DIO) digital pin number","DefaultValue":"8","Type":"pin;TM1638 DIO","Condition":"TM1638_ENABLEDMODULES > 0"}
#define TM1638_CLK 7            //{"Name":"TM1638_CLK","Title":"Common clock (CLK) digital pin number","DefaultValue":"7","Type":"pin;TM1638 CLK","Condition":"TM1638_ENABLEDMODULES > 0"}
#define TM1638_STB1 9           //{"Name":"TM1638_STB1","Title":"1st module strobe (STB0) digital pin number","DefaultValue":"9","Type":"pin;TM1638 STB1","Condition":"TM1638_ENABLEDMODULES > 0"}
#define TM1638_SINGLECOLOR1 0   //{"Name":"TM1638_SINGLECOLOR1","Title":"1st module is single color","DefaultValue":"0","Type":"bool","Condition":"TM1638_ENABLEDMODULES > 0"}

#define TM1638_STB2 10          //{"Name":"TM1638_STB2","Title":"2nd module strobe (STB1) digital pin number","DefaultValue":"10","Type":"pin;TM1638 STB2","Condition":"TM1638_ENABLEDMODULES > 1"}
#define TM1638_SINGLECOLOR2 0   //{"Name":"TM1638_SINGLECOLOR2","Title":"2nd module is single color","DefaultValue":"0","Type":"bool","Condition":"TM1638_ENABLEDMODULES > 1"}

#define TM1638_STB3 11          //{"Name":"TM1638_STB3","Title":"3rd module strobe (STB2) digital pin number","DefaultValue":"11","Type":"pin;TM1638 STB3","Condition":"TM1638_ENABLEDMODULES > 2"}
#define TM1638_SINGLECOLOR3 0   //{"Name":"TM1638_SINGLECOLOR3","Title":"3rd module is single color","DefaultValue":"0","Type":"bool","Condition":"TM1638_ENABLEDMODULES > 2"}

#define TM1638_STB4 12          //{"Name":"TM1638_STB4","Title":"4th module strobe (STB3) digital pin number","DefaultValue":"12","Type":"pin;TM1638 STB4","Condition":"TM1638_ENABLEDMODULES > 3"}
#define TM1638_SINGLECOLOR4 0   //{"Name":"TM1638_SINGLECOLOR4","Title":"4th module is single color","DefaultValue":"0","Type":"bool","Condition":"TM1638_ENABLEDMODULES > 3"}

#define TM1638_STB5 0           //{"Name":"TM1638_STB5","Title":"5th module strobe (STB4) digital pin number","DefaultValue":"0","Type":"pin;TM1638 STB5","Condition":"TM1638_ENABLEDMODULES > 4"}
#define TM1638_SINGLECOLOR5 0   //{"Name":"TM1638_SINGLECOLOR5","Title":"5th module is single color","DefaultValue":"0","Type":"bool","Condition":"TM1638_ENABLEDMODULES > 4"}

#define TM1638_STB6 0           //{"Name":"TM1638_STB6","Title":"6th module strobe (STB5) digital pin number","DefaultValue":"0","Type":"pin;TM1638 STB6","Condition":"TM1638_ENABLEDMODULES > 5"}
#define TM1638_SINGLECOLOR6 0   //{"Name":"TM1638_SINGLECOLOR6","Title":"6th module is single color","DefaultValue":"0","Type":"bool","Condition":"TM1638_ENABLEDMODULES > 5"}

#include "SHTM1638.h"
#endif

// -------------------------------------------------------------------------------------------------------
// TM1637 Modules ----------------------------------------------------------------------------------------
// http://www.dx.com/p/0-36-led-4-digit-display-module-for-arduino-black-blue-works-with-official-arduino-boards-254978
// -------------------------------------------------------------------------------------------------------
// Number of Connected TM1637 modules
// 0 disabled, > 0 enabled
#define TM1637_ENABLEDMODULES 0 //{"Group":"TM1637 7 Segment Modules","Name":"TM1637_ENABLEDMODULES","Title":"TM1637 modules connected","DefaultValue":"0","Type":"int","Max":8}
#ifdef INCLUDE_TM1637

#define TM1637_DIO1 4           //{"Name":"TM1637_DIO1","Title":"1st TM1637 DIO digital pin number","DefaultValue":"4","Type":"pin;TM1637 #1 DIO","Condition":"TM1637_ENABLEDMODULES >=1"}
#define TM1637_CLK1 3           //{"Name":"TM1637_CLK1","Title":"1st TM1637 CLK digital pin number","DefaultValue":"3","Type":"pin;TM1637 #1 CLK","Condition":"TM1637_ENABLEDMODULES >=1"}
#define TM1637_DIO2 4           //{"Name":"TM1637_DIO2","Title":"2nd TM1637 DIO digital pin number","DefaultValue":"4","Type":"pin;TM1637 #2 DIO","Condition":"TM1637_ENABLEDMODULES >=2"}
#define TM1637_CLK2 3           //{"Name":"TM1637_CLK2","Title":"2nd TM1637 CLK digital pin number","DefaultValue":"3","Type":"pin;TM1637 #2 CLK","Condition":"TM1637_ENABLEDMODULES >=2"}
#define TM1637_DIO3 4           //{"Name":"TM1637_DIO3","Title":"3rd TM1637 DIO digital pin number","DefaultValue":"4","Type":"pin;TM1637 #3 DIO","Condition":"TM1637_ENABLEDMODULES >=3"}
#define TM1637_CLK3 3           //{"Name":"TM1637_CLK3","Title":"3rd TM1637 CLK digital pin number","DefaultValue":"3","Type":"pin;TM1637 #3 CLK","Condition":"TM1637_ENABLEDMODULES >=3"}
#define TM1637_DIO4 4           //{"Name":"TM1637_DIO4","Title":"4th TM1637 DIO digital pin number","DefaultValue":"4","Type":"pin;TM1637 #4 DIO","Condition":"TM1637_ENABLEDMODULES >=4"}
#define TM1637_CLK4 3           //{"Name":"TM1637_CLK4","Title":"4th TM1637 CLK digital pin number","DefaultValue":"3","Type":"pin;TM1637 #4 CLK","Condition":"TM1637_ENABLEDMODULES >=4"}
#define TM1637_DIO5 4           //{"Name":"TM1637_DIO5","Title":"5th TM1637 DIO digital pin number","DefaultValue":"4","Type":"pin;TM1637 #5 DIO","Condition":"TM1637_ENABLEDMODULES >=5"}
#define TM1637_CLK5 3           //{"Name":"TM1637_CLK5","Title":"5th TM1637 CLK digital pin number","DefaultValue":"3","Type":"pin;TM1637 #5 CLK","Condition":"TM1637_ENABLEDMODULES >=5"}
#define TM1637_DIO6 4           //{"Name":"TM1637_DIO6","Title":"6th TM1637 DIO digital pin number","DefaultValue":"4","Type":"pin;TM1637 #6 DIO","Condition":"TM1637_ENABLEDMODULES >=6"}
#define TM1637_CLK6 3           //{"Name":"TM1637_CLK6","Title":"6th TM1637 CLK digital pin number","DefaultValue":"3","Type":"pin;TM1637 #6 CLK","Condition":"TM1637_ENABLEDMODULES >=6"}
#define TM1637_DIO7 4           //{"Name":"TM1637_DIO7","Title":"7th TM1637 DIO digital pin number","DefaultValue":"4","Type":"pin;TM1637 #7 DIO","Condition":"TM1637_ENABLEDMODULES >=7"}
#define TM1637_CLK7 3           //{"Name":"TM1637_CLK7","Title":"7th TM1637 CLK digital pin number","DefaultValue":"3","Type":"pin;TM1637 #7 CLK","Condition":"TM1637_ENABLEDMODULES >=7"}
#define TM1637_DIO8 4           //{"Name":"TM1637_DIO8","Title":"8th TM1637 DIO digital pin number","DefaultValue":"4","Type":"pin;TM1637 #8 DIO","Condition":"TM1637_ENABLEDMODULES >=8"}
#define TM1637_CLK8 3           //{"Name":"TM1637_CLK8","Title":"8th TM1637 CLK digital pin number","DefaultValue":"3","Type":"pin;TM1637 #8 CLK","Condition":"TM1637_ENABLEDMODULES >=8"}

#include "SHTM1637.h"

#endif

// -------------------------------------------------------------------------------------------------------
// TM1637 6 DIGITS Modules ----------------------------------------------------------------------------------------
// http://www.dx.com/p/0-36-led-4-digit-display-module-for-arduino-black-blue-works-with-official-arduino-boards-254978
// -------------------------------------------------------------------------------------------------------
// Number of Connected TM1637 modules
// 0 disabled, > 0 enabled
#define TM1637_6D_ENABLEDMODULES 0 //{"Group":"TM1637 6Digits 7 Segment Modules","Name":"TM1637_6D_ENABLEDMODULES","Title":"TM1637 modules connected","DefaultValue":"0","Type":"int","Max":8}
#ifdef INCLUDE_TM1637_6D
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
void loop() {
#ifdef INCLUDE_SHAKEITL298N
	shShakeitL298N.safetyCheck();
#endif
#ifdef INCLUDE_SHAKEITMOTOMONSTER
	shShakeitMotoMonster.safetyCheck();
#endif
#ifdef INCLUDE_SHAKEIDUALVNH5019
	shShakeitDualVNH5019.safetyCheck();
#endif
#ifdef INCLUDE_SHAKEITADASHIELD
	shShakeitAdaMotorShieldV2.safetyCheck();
#endif
#ifdef INCLUDE_SHAKEITDKSHIELD
	shShakeitDKMotorShield.safetyCheck();
#endif
#ifdef INCLUDE_SHAKEITPWM
	shShakeitPWM.safetyCheck();
#endif
#ifdef INCLUDE_SHAKEITPWMFANS
	shShakeitPWMFans.safetyCheck();
#endif
#ifdef INCLUDE_GAMEPAD
	UpdateGamepadState();
#endif

	shCustomProtocol.loop();

	// Wait for data
	if (FlowSerialAvailable() > 0) {
		if (FlowSerialTimedRead() == MESSAGE_HEADER)
		{
			lastSerialActivity = millis();
			// Read command
			loop_opt = FlowSerialTimedRead();

			if (loop_opt == '1') Command_Hello();
			else if (loop_opt == '8') Command_SetBaudrate();
			else if (loop_opt == 'J') Command_ButtonsCount();
			else if (loop_opt == '2') Command_TM1638Count();
			else if (loop_opt == 'B') Command_SimpleModulesCount();
			else if (loop_opt == 'A') Command_Acq();
			else if (loop_opt == 'N') Command_DeviceName();
			else if (loop_opt == 'I') Command_UniqueId();
			else if (loop_opt == '0') Command_Features();
			else if (loop_opt == '3') Command_TM1638Data();
			else if (loop_opt == 'V') Command_Motors();
			else if (loop_opt == 'S') Command_7SegmentsData();
			else if (loop_opt == '4') Command_RGBLEDSCount();
			else if (loop_opt == '6') Command_RGBLEDSData();
			else if (loop_opt == 'R') Command_RGBMatrixData();
			else if (loop_opt == 'M') Command_MatrixData();
			else if (loop_opt == 'G') Command_GearData();
			else if (loop_opt == 'L') Command_I2CLCDData();
			else if (loop_opt == 'K') Command_GLCDData(); // Nokia | OLEDS
			else if (loop_opt == 'P') Command_CustomProtocolData();
			else if (loop_opt == 'X')
			{
				String xaction = FlowSerialReadStringUntil(' ', '\n');
				if (xaction == F("list")) Command_ExpandedCommandsList();
				else if (xaction == F("mcutype")) Command_MCUType();
				else if (xaction == F("tach")) Command_TachData();
				else if (xaction == F("speedo")) Command_SpeedoData();
				else if (xaction == F("boost")) Command_BoostData();
				else if (xaction == F("temp")) Command_TempData();
				else if (xaction == F("fuel")) Command_FuelData();
				else if (xaction == F("cons")) Command_ConsData();
				else if (xaction == F("encoderscount")) Command_EncodersCount();
			}
		}
	}

	if (millis() - lastSerialActivity > 5000) {
		Command_Shutdown();
	}
}

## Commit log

2022-08-09 new features
    [7seg_display.kicad_sch, GDBM.kicad_pcb, GDBM.kicad_sch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]
2022-08-12 changed to match simhub conf
    [7seg_display.kicad_sch, GDBM.kicad_sch, interfaces2.kicad_sch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]
2022-08-13 maybe ok
    [GDBM Rev 1 BOM for Digi-Key.xlsx, GDBM.csv, GDBM.kicad_pcb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]
2022-08-17 PSU and LED powering changed
    [7seg_display.kicad_sch, GDBM.csv, GDBM.kicad_pcb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]
2022-08-17 PSU fixes
    [GDBM.kicad_pcb, main.kicad_sch, psu.kicad_sch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]
2022-08-26 Prototype v1
    [GDBM.kicad_pcb]
2023-01-05 bugfixes
    added 555 circuit for brightness control
    [GDBM.csv, GDBM.kicad_pcb, GDBM.kicad_sch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]
2023-02-05 Added a ferrite and silk screen markings
    [GDBM.kicad_pcb, GDBM.kicad_sch, buttonui.kicad_sch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]
2023-02-26 BOM generated
    [GDBM Rev 2.00.csv, GDBM Rev 2.00_purchase.xlsx, GDBM.csv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]
2023-02-28 led buffer added
    [GDBM Rev 2.00.csv, GDBM Rev 2.00_purchase.xlsx, GDBM.csv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]
2023-03-03 change to kicad 7
    [7seg_display.kicad_sch, GDBM.kicad_pcb, GDBM.kicad_sch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]
2023-03-18 new kicad version
2023-03-18 Update GDBM Rev 2.00 BOM ibom.html
2023-03-19 Update GDBM Rev 2.00 BOM ibom.html
    populated
2023-03-27 LED order changed again
    [GDBM.kicad_sch, led_driver.kicad_sch, rev_history.kicad_sch]
2023-03-27 FW to match PCB 2.0
2023-03-27 Create GDBM Schematic Rev 2.00.pdf
2023-03-29 R33 value change
    [7seg_display.kicad_sch, GDBM.kicad_pcb, GDBM.kicad_sch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]
2023-05-28 Laser cut vectors
    [RGB Diffuser v5 - Body1.dxf, RGB diffuser.dxf]
2023-10-09 version numbering fix
    [7seg_display.kicad_sch, GDBM.kicad_sch, buttonui.kicad_sch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]
2023-11-11 Documentation update
    [7seg_display.kicad_sch, led_driver.kicad_sch]
2024-07-11 Documentation and version update
    [7seg_display.kicad_sch, GDBM.kicad_pcb, GDBM.kicad_sch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]
